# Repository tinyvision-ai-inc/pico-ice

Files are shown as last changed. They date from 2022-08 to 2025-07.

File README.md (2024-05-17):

# pico-ice

[Doc](http://pico-ice.tinyvision.ai/)
| [Hardware](https://github.com/tinyvision-ai-inc/pico-ice)
| [SDK](https://github.com/tinyvision-ai-inc/pico-ice-sdk)
| [Schematic](https://raw.githubusercontent.com/tinyvision-ai-inc/pico-ice/main/Board/Rev3/pico-ice.pdf)
| [Assembly](https://htmlpreview.github.io/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)
| [Discord](https://discord.gg/t2CzbAYeD2)

Elecrow (https://www.elecrow.com/pico-ice-rp2040-plus-lattice-ice40up5k-fpga.html)



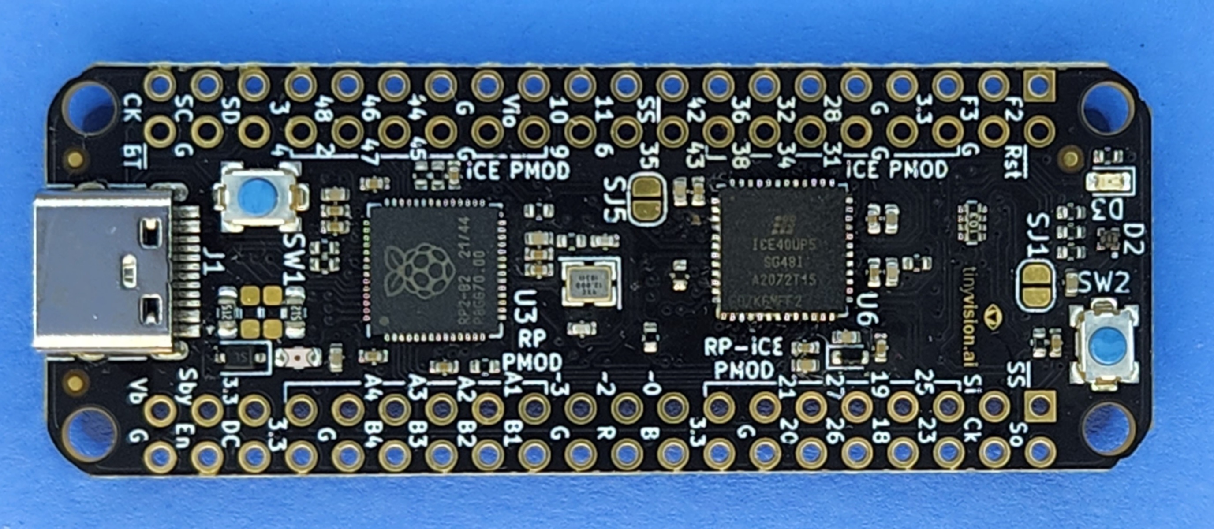
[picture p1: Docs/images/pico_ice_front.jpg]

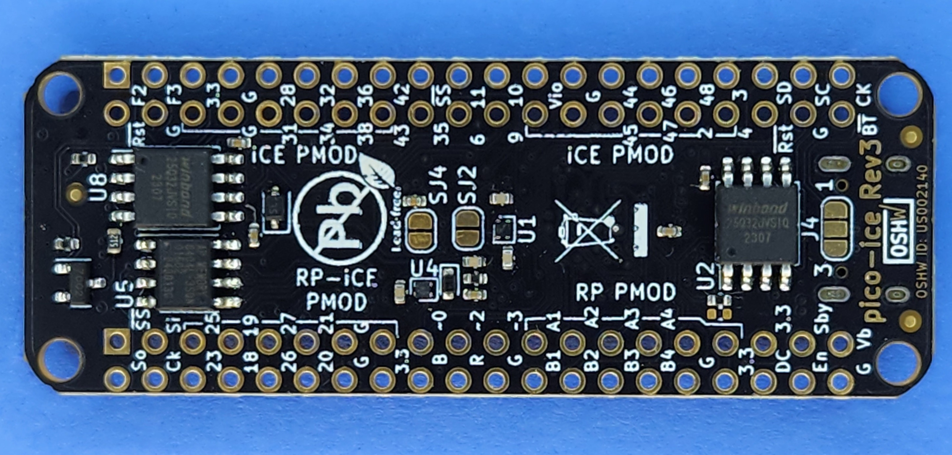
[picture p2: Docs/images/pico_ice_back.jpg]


## PCB Design Files, Designs, Documentation

The pico-ice is a small, low cost board with the Raspberry Pi Pico processor (RP2040) and a Lattice Semiconductor iCE40UP5K FPGA. The board features independent flash for the FPGA and RP2040, low power SSRAM, a couple of pushbuttons and a 3 color LED with _all_ FPGA and RP2040 pins brought out to easy to use 0.1" header pins (arranged as PMOD's) for fast prototyping.

The tinyVision.ai pico-ice Board Features:

* RaspberryPi RP2040 processor
* Lattice UltraPlus ICE40UP5K FPGA with 5.3K LUTs, 1Mb SPRAM, 120Kb DPRAM, 8 Multipliers
* _ALL_ RP2040 and 32 FPGA GPIO on 0.1” headers
* 4MB SPI Flash
* 8MB low power qSPI SRAM
* RGB LED, shared between the RP2040 and FPGA
* 2 pushbuttons, 1 dedicated and 1 primarily for processor reset during development but can be repurposed for user applications when not used for reset
* On board 3.3V and 1.2V Regulators, can supply 3.3V to your project
* Open source schematic and layout using KiCAD design tools
* 4 layer board with a solid ground plane for good signal integrity
* FPGA clock supplied by the RP2040, easy to program FPGA clock under SW control
* Examples for communicating to the FPGA over SPI
* Support for ultra low power sleeep mode: can shut down the RP2040 and FPGA while keeping the SRAM powered

Firmware features:
* pico-ice library to support drag-drop programming of the FPGA bitfile: no need of any dedicated programmer
* Alternate programming of the FPGA flash using DFU mode
* FPGA clock under RP2040 control
* Passthrough UART code enables transparent access to the FPGA's UART for debug/logging/control

[OSHW US002140](https://certification.oshwa.org/us002140.html) | Certified open source hardware | oshwa.org/cert

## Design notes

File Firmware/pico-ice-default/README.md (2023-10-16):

# Default Firmware

Downloads: [releases](https://github.com/tinyvision-ai-inc/pico-ice/releases/)

- A first USB-UART (#0) is used for the and a REPL command line interface
  for now only showing help message and version information.

- A second USB-UART (#1) is used for mirroring everything between
  this USB interface UART TX on RP0 with ICE27, UART RX on RP1 with ICE25.

- A third USB-UART (#2) is exchanging data with the main SPI bus onboard
  ([doc](https://pico-ice.tinyvision.ai/ice_usb.html#usb-spi-fpgasramflash-forwarding)).

- A 12 MHz clock is exported from the RP2040 pin 24 toward the iCE40 pin 35.

- An USB DFU interface allows programming through [dfu-utils](https://dfu-util.sourceforge.net/)
  as shipped with [oss-cad-suite](https://github.com/YosysHQ/oss-cad-suite-build).

- An USB MSC interface allows programming the board by copying a file to an USB device
  ([doc](https://pico-ice.tinyvision.ai/programming_the_fpga.html#using-a-drag-drop-or-file-copy-scheme)).

See the [documentation](https://pico-ice.tinyvision.ai/) for how to use them.

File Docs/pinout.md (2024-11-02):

# Pinout Diagram

This diagram shows the ICE40 and RP2040 names for the through holes on the pico-ice board. 

pinout diagram

[SVG](pinout/pinout.svg)
| [PNG](pinout/pinout.png)
| [RP2040](https://www.raspberrypi.com/documentation/pico-sdk/hardware.html#autotoc_md0)
| [ICE40](https://www.latticesemi.com/view_document?document_id=51971)

## With RTL on the iCE40

To program the FPGA, one needs to tell the synthesis tools which pins to connect to the signals in your RTL.  There are two different ways to name the pins.   The wafer names are words like `IOB_6a` and `IOT_8b`, and the pin numbers have names like `ICE_2`, `ICE_3`, and `ICE_4`.
Both sets of names can be found in this [PCF file](https://github.com/tinyvision-ai-inc/pico-ice-sdk/blob/main/rtl/pico_ice.pcf).

For Amaranth, until this gets upstreamed, the various board resources including its pins are defined on
[`pico_ice.py`](https://github.com/tinyvision-ai-inc/pico-ice-sdk/blob/main/amaranth/pico_ice.py).

## With code on the RP2040

The FPGA pins and other signals are defined in [`pico_ice.h`](https://github.com/tinyvision-ai-inc/pico-ice-sdk/blob/main/include/boards/pico_ice.h).

The PMOD pins can also be accessed from
[`pmod.h`](https://github.com/tinyvision-ai-inc/pico-ice-sdk/blob/main/include/pmod.h) and
[`ice_pmod.h`](https://github.com/tinyvision-ai-inc/pico-ice-sdk/blob/main/include/ice_pmod.h).

## SPI Pinouts 

For debugging the FPGA <-> SPI <-> Flash/RAM interface it is very helpful to use the 4 through holes on the upper right of the FPGA, and to connect a logic analyzer to the upper right PMOD.  These two diagrams may help.  Remember that the default boot process leaves the Flash switched ``off``.  With the Yosys icepack command, the ``-s`` option boots the Flash in the ``on`` state. 

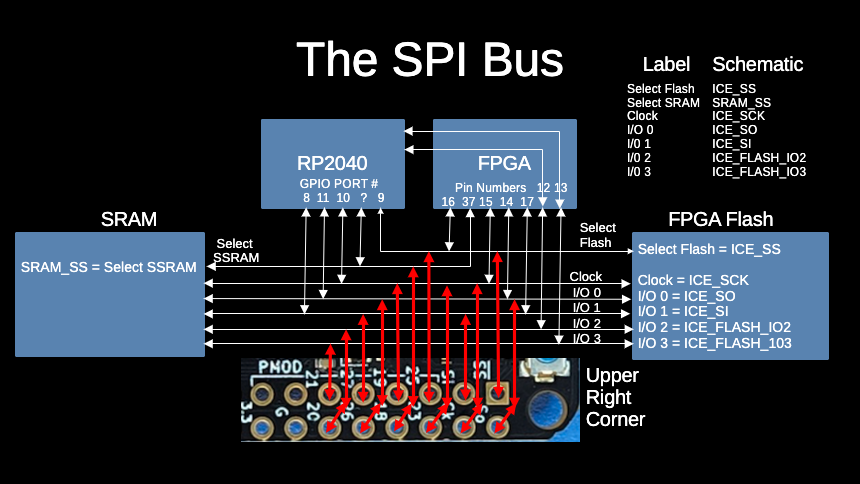
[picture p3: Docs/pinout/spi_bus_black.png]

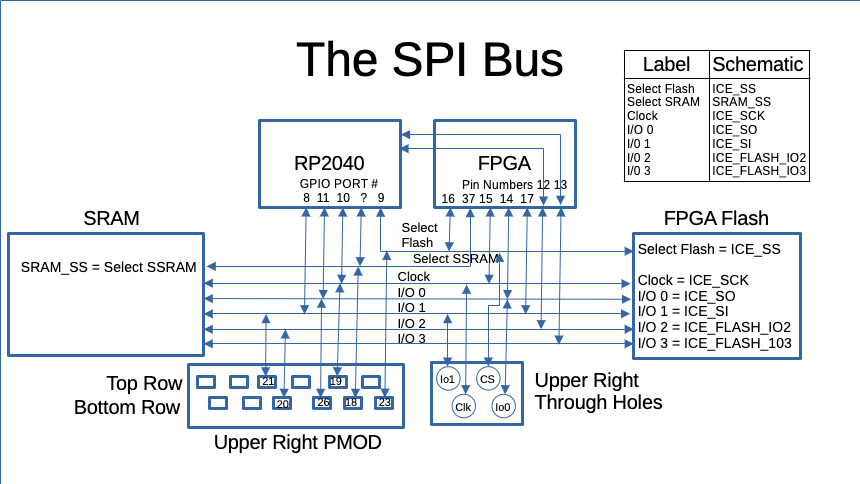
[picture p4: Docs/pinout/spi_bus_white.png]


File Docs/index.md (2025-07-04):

[Doc](http://pico-ice.tinyvision.ai/)
| [Hardware](https://github.com/tinyvision-ai-inc/pico-ice)
| [SDK](https://github.com/tinyvision-ai-inc/pico-ice-sdk)
| [Schematic](https://raw.githubusercontent.com/tinyvision-ai-inc/pico-ice/main/Board/Rev3/pico-ice.pdf)
| [Assembly](https://htmlpreview.github.io/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)
| [Discord](https://discord.gg/t2CzbAYeD2)

Elecrow (https://www.elecrow.com/pico-ice-rp2040-plus-lattice-ice40up5k-fpga.html)



The pico-ice is a small, low cost board with the Raspberry Pi Pico processor ([RP2040](https://www.raspberrypi.com/documentation/microcontrollers/rp2040.html)) and a Lattice Semiconductor [iCE40UP5K](https://www.latticesemi.com/en/Products/FPGAandCPLD/iCE40UltraPlus) FPGA. The board features independent flash for the FPGA and RP2040, low power SSRAM, a couple of pushbuttons and a 3 color LED with _all_ FPGA and RP2040 pins brought out to easy to use 0.1" header pins (arranged as Pmod's) for fast prototyping.




Board Hardware Features:

* Raspberry Pi RP2040 processor
* Lattice UltraPlus ICE40UP5K FPGA with 5.3k LUTs, 1Mb SPRAM, 120Kb DPRAM, 8 Multipliers
* _ALL_ RP2040 and 32 FPGA GPIO on 0.1” headers
* 4MB SPI Flash
* 8MB low power qSPI SRAM
* RGB LED, shared between the RP2040 and FPGA
* 2 pushbuttons, 1 dedicated and 1 primarily for processor reset during development but can be repurposed for user applications when not used for reset
* On board 3.3V and 1.2V Regulators, can supply 3.3V to your project
* Open source schematic and layout using KiCAD design tools
* 4 layer board with a solid ground plane for good signal integrity

Board Firmware features:

* FPGA clock supplied by the RP2040, easy to program FPGA clock under SW control
* RP2040 can program the FPGA in various ways
* Examples for communicating to the FPGA from USB to UART or SPI
* Support for ultra low power sleeep mode: can shut down the RP2040 and FPGA while keeping the SRAM powered

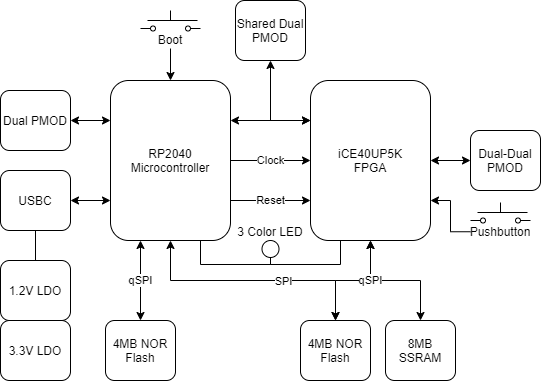
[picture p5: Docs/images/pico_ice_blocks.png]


[OSHW US002140](https://certification.oshwa.org/us002140.html) | Certified open source hardware | oshwa.org/cert

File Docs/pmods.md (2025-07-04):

# Using Pmods

The Pmod Connection system is using a grid of 2 rows and 6 columns of pins.

It was designed by Digilent to offer something compatible with both classical jumper wires used on breadboards,
and a standardised pinout that supports multiple protocols on the same connector.

This is popular on FPGA boards as it permits them to support any protocol over
the same connector with the right pinout, rarely possible on MCUs.

This standard is documented [here](https://reference.digilentinc.com/_media/reference/pmod/pmodoledrgb/pmodoledrgb_sch.pdf).

## Pmod in the pico-ice

Here is an [example of how to solder](md_getting__started.html#autotoc_md2) the Pmod connectors.

There are 4 Pmod connectors in the pico-ice, numbered clockwise from 1 to 4 starting from the USB connector.

- 2 connected to the iCE40
- 1 connected to both the RP2040 and iCE40
- 1 connected to the RP2040

The pinout of the RP2040 is made to be compatible with SPI0,
with the other protocols that may be bit-banged or implemented with PIO to be pin-compatible.

For the iCE40, the pin numbers are available from
[pico_ice.pcf](https://github.com/tinyvision-ai-inc/pico-ice-sdk/blob/main/rtl/pico_ice.pcf).

For the RP2040, the pin numbers are available from
[ice_pmod.h](https://github.com/tinyvision-ai-inc/pico-ice-sdk/blob/main/include/ice_pmod.h).

You can then use any of the pinout declaration described
[here](https://github.com/tinyvision-ai-inc/pico-ice-sdk/blob/main/include/pmod.h).

    // Use the pins from their GPIO names
    gpio_init(ice_pmod_3.gpio.io1);
    gpio_init(ice_pmod_3.gpio.io2);
    gpio_init(ice_pmod_3.gpio.io3);
    gpio_init(ice_pmod_3.gpio.io4);
    gpio_init(ice_pmod_3.gpio.io7);
    gpio_init(ice_pmod_3.gpio.io8);
    gpio_init(ice_pmod_3.gpio.io9);
    gpio_init(ice_pmod_3.gpio.io10);

    // Use the pins from their I²C names
    gpio_init(ice_pmod_3.i2c.sda);
    gpio_init(ice_pmod_3.i2c.scl);

    // Use the pins from their UART names
    gpio_init(ice_pmod_3.i2c.tx);
    gpio_init(ice_pmod_3.i2c.rx);

    // Use the pins from their SPI names
    gpio_set_function(ice_pmod_3.spi.copi, FUNC_SPI);
    gpio_set_function(ice_pmod_3.spi.cipo, FUNC_SPI);
    gpio_set_function(ice_pmod_3.spi.clk, FUNC_SPI);

    // Access the top or bottom row individually
    gpio_set_function(ice_pmod_3.row.top.spi.copi, FUNC_SPI);
    gpio_set_function(ice_pmod_3.row.bottom.spi.copi, FUNC_SPI);

    [...]

## Pmod Modules

There are many Pmod vendors, and this page attempts to enumerate as many as possible.

If you have made a Pmod module, let us know and we would add it to this list!

- <https://www.infineon.com/cms/en/search.html#!term=pmod&view=products>
- <https://digilent.com/shop/boards-and-components/system-board-expansion-modules/pmods/>
- <https://www.renesas.com/us/en/software-tool/quick-connect-iot-platform>
- <https://www.tindie.com/stores/johnnywu/>
- <https://1bitsquared.com/collections/fpga>
- <https://www.tindie.com/search/?q=pmod>
- <https://lectronz.com/products/search?q=pmod>
- <https://www.aries-embedded.com/evaluation-kit/tools/pmod-extension-module>
- <https://github.com/wuxx/icesugar/tree/master/schematic>
- <https://machdyne.com/?s=pmod&post_type=product>
- <https://aliexpress.com/store/912189181/search?SearchText=pmod>
- <https://github.com/swetland/ethernet-pmod>
- <https://fpga.fm4dd.com/>
- <https://github.com/icebreaker-fpga/icebreaker-pmod>
- <https://blackmesalabs.wordpress.com/>
- <https://www.solder.party/docs/keyboard-pmod/pmod-to-qwiic-adapter/>
- <https://github.com/marcinwachowiak/pmod-pdm-microphone-array/>
- <https://github.com/apfelaudio/eurorack-pmod>

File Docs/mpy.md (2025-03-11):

# Micropython

Pico-ice and pico2-ice support micropython.

## To install
- Acquire the latest release for the device you have from: https://github.com/tinyvision-ai-inc/pico-ice-micropython/releases
- Flash the device as normal (uf2 pasted in the RP2 disk)

## To use
The API to use the FPGA is as follow:
- `ice` is the microypthon module: `import ice`
- `fpga` is the class provided by the module to manage the ICE40 FPGA `ice.fpga(...)`
- `fpga` provides the methods `stop()`, `start()`, and `cram(file)`

## How to program a bitstream to the FPGA RAM

- The Pin class is imported from the machine module to provide interfacing with the hardware.
- The module is imported
- The fpga type is configured with the approriate pins for the device, as well as the frequency (in MHz) that the FPGA will run at.
- The bitstream file is opened, in byte (as opposed to text) mode (`b`), to read (`r`).
- The fpga is brought out of reset with `fpga.start()`
- The bitstream is loaded into the FPGA using `fpga.cram(file)` with the previously opened file as argument.

### On pico-ice:

```python
from machine import Pin
import ice
fpga = ice.fpga(cdone=Pin(26), clock=Pin(24), creset=Pin(27), cram_cs=Pin(9), cram_mosi=Pin(8), cram_sck=Pin(10), frequency=48)
file = open("bitstream.bin", "br")
fpga.start()
fpga.cram(file)
```

### On pico2-ice:

```python
from machine import Pin
import ice
fpga = ice.fpga(cdone=Pin(40), clock=Pin(21), creset=Pin(31), cram_cs=Pin(5), cram_mosi=Pin(4), cram_sck=Pin(6), frequency=48)
file = open("bitstream.bin", "br")
fpga.start()
fpga.cram(file)
```

## How to program a bistream to the FPGA Flash (persistent bitstream)

### On pico-ice:

```python
from machine import Pin
import ice
file = open("bitstream.bin", "br")
flash = ice.flash(miso=Pin(8), mosi=Pin(11), sck=Pin(10), cs=Pin(9))
flash.erase(4096) # Optional
flash.write(file)
# Optional
fpga = ice.fpga(cdone=Pin(26), clock=Pin(24), creset=Pin(27), cram_cs=Pin(9), cram_mosi=Pin(8), cram_sck=Pin(10), frequency=48)
fpga.start()
```

### On pico2-ice:

```python
from machine import Pin
import ice
file = open("bitstream.bin", "br")
flash = ice.flash(miso=Pin(4), mosi=Pin(7), sck=Pin(6), cs=Pin(5))
flash.erase(4096) # Optional
flash.write(file)
# Optional
fpga = ice.fpga(cdone=Pin(40), clock=Pin(21), creset=Pin(31), cram_cs=Pin(5), cram_mosi=Pin(4), cram_sck=Pin(6), frequency=48)
fpga.start()
```

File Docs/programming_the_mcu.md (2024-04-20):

# Programming the RP2040

To upload a new firmware image on the PR2040 (the "pico" part of "pico-ice"), you need to switch to that RP2040 UF2 bootloader mode instead of the FPGA UF2 mode.

You can do that by connecting a jumper between the `BT` pin a `Gnd` pin, then press the `RESET` button:

1. Connect the `USB_BOOT` pin to ground. For instance with a pair of tweezers, a jumper, or an uncoated paper clip.

2. Press and release the "RESET" button. The RP2040 now bypasses its firmware, and runs the RP2040 factory bootloader (from internal ROM) instead.

3. Disconnect the `USB_BOOT` pin from ground.

4. Look for an USB drive named `RPI-RP2` and mount it, open it, and check that there are only 2 files in it: `INFO.HTML` and `INFO_UF2.TXT`.
   If you also have an `CURRENT.UF2`, this means you found the FPGA flashing interface, and need to retry steps 1 and 2.

5. Copy the `.uf2` firmware file onto the USB drive.

6. Eject the USB drive.
   At this step, the firmware should be uploaded and running.

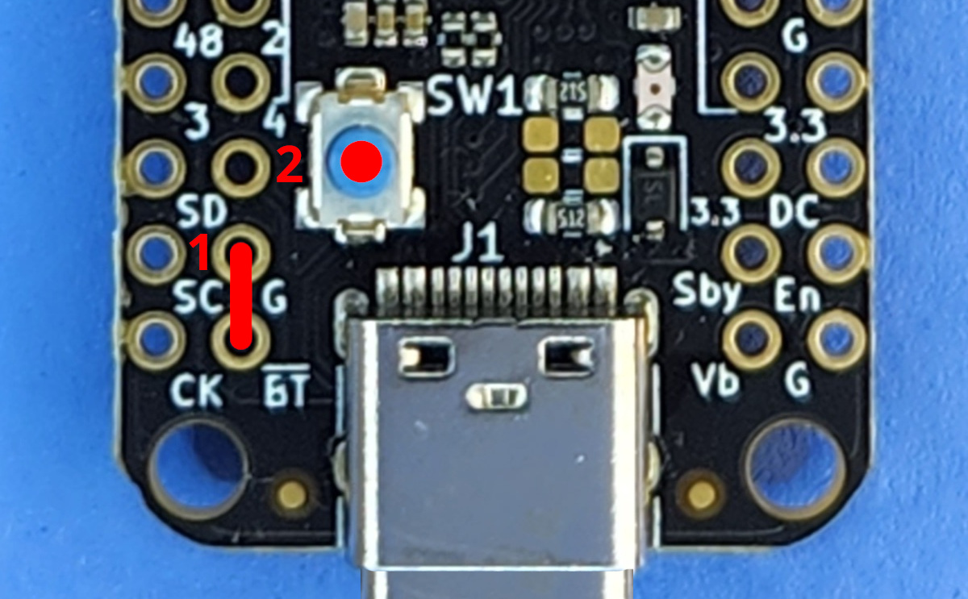
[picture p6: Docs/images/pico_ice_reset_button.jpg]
photo of which pins to short


Since version [`v1.6.1`](https://github.com/tinyvision-ai-inc/pico-ice/releases),
it is possible to reboot the pico-ice into bootloader "BOOTSEL" mode without jumpers:

    picocom --baud 1200 /dev/ttyACM0

This uses the [convention established by Arduino boards](https://arduino.github.io/arduino-cli/dev/platform-specification/#1200-bps-bootloader-reset)
which reset into bootloader mode when connecting with baud 1200.

After this, it becomes possible to use the [picotool](https://github.com/raspberrypi/picotool) to control the firmware (upload, check version, reboot):

    $ sudo picotool info
    Program Information
     name:      pico_ice_default
     features:  USB stdin / stdout

## Troubleshooting

### RPI-RP2 is still visible after step 6

This means the device remained in "bootloader" mode.
One thing to check is that the `USB_BOOT` pin (marked `BT` on the board) is not connected to anything anymore,
then try to reset the board.

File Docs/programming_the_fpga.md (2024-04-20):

# Programming the iCE40

The FPGA normally boots from a dedicated serial NOR flash.
This flash can be programmed by the Pico processor which exposes the flash to the host OS as either a removable drive or a DFU endpoint.

On Windows, while the RaspberryPi guide mentions using Visual Studio Code with a plugin a an IDE, better results were obtained by using the [WSL2 environment](https://learn.microsoft.com/en-us/windows/wsl/install).

## Using a drag and drop file copy

You would need a compiler toolchain installed for building the [UF2 Utils](https://github.com/tinyvision-ai-inc/uf2-utils) on your system.
On Windows, you can use <https://github.com/microsoft/uf2> instead,
which contains [uf2conv.py](https://github.com/microsoft/uf2/blob/master/utils/uf2conv.md).

Out of the box, the [default firmware](https://github.com/tinyvision-ai-inc/pico-ice/releases/) should already be present on your board.
You can skip step 1 if this is the case.

1.  If you changed the default firwmare, [program](md_programming__the__mcu.html) it again onto the RP2040.
    You can also integrate the FPGA programming code in your own firmware with [ice_usb](group__ice__usb.html).

2.  Install or build the [UF2 Utils](https://github.com/tinyvision-ai-inc/uf2-utils),
    and a [blinky example](https://github.com/tinyvision-ai-inc/UPduino-v3.0/blob/master/RTL/blink_led/rgb_blink.bin) for any iCE40 board.

3.  Convert the binary bitstream `rgb_blink.bin` into an UF2 `rgb_blink.uf2` with the UF2 Utils:

        $ bin2uf2 -o rgb_blink.uf2 rgb_blink.bin

4.  Connect the pico-ice via USB and lookup the USB drive named `pico-ice`. Open it.

5.  You can copy the `rgb_blink.uf2` file to that drive you just attached.
    As soon as you copy the file over,t he pico-ice will reboot and allow the FPGA to come up depending on the code running in the Pico processor.

## Using the DFU mode

1.  If you changed the default firwmare, [program](md_programming__the__mcu.html) it again onto the RP2040.
    You can also integrate the FPGA programming code in your own firmware with [ice_usb](group__ice__usb.html).

2.  Install the DFU utilities.

    a.  For Windows, [yosys-hq tabby-cad](https://www.yosyshq.com/tabby-cad-datasheet):
        double-clicking on `start.bat` on the OSS CAD Suite installation opens a prompt with the dfu-util command available.

    b.  For other systems you can install the [dfu-util](https://repology.org/project/dfu-util/versions) package.

3.  Check whether the Pico is recognized as a DFU device: `dfu-util -l`.
    This should list the pico-ice as a DFU device:

        Found DFU: [1209:b1c0] ver=0100, devnum=105, cfg=1, intf=0, path="1-4.4", alt=0, name="iCE40 DFU (flash)", serial="DE62A435436F5939"
        Found DFU: [1209:b1c0] ver=0100, devnum=105, cfg=1, intf=0, path="1-4.4", alt=1, name="iCE40 DFU (CRAM)", serial="DE62A435436F5939"

4.  Download the FPGA bin file to the pico-ice.
    The Pico can be rebooted as soon as the download succeeds with the `-R` flag.

        $ dfu-util --alt 0 --download rgb_blink.bin --reset  # to flash
        $ dfu-util --alt 1 --download rgb_blink.bin          # to volatile memory

## Using APIO

The [APIO](https://github.com/FPGAwars/apio) project is a command line tool to fetch and use
the [oss-cad-suite](https://github.com/YosysHQ/oss-cad-suite-build) FPGA toolchain based
on [Yosys](https://github.com/YosysHQ/).

It will bring an up-to-date build environment running quickly.

On Windows, you will first need to setup the `libusbK` driver for `pico-ice DFU (CRAM)`
[with Zadig](https://zadig.akeo.ie/) or [with UsbDriverTool](https://visualgdb.com/UsbDriverTool/)
([doc](https://github.com/FPGAwars/apio/wiki/Quick-start)).

    # Download the latest APIO dev version (with pico-ice support):
    pip3 install git+https://github.com/FPGAwars/apio

    # Download and install oss-cad-suite
    apio install -a
    
    # Build a new directory with a "blinky" example project inside
    mkdir pico-ice-blinky; cd pico-ice-blinky
    apio examples -f iCE40-UP5K/blink

    # Set the board to "pico-ice"
    apio init --sayyes --board pico-ice

    # Build the project using yosys/nextpnr
    apio build

    # Plug your pico-ice board and upload the blinky project to it
    apio upload

If `apio upload` fails, it is also possible to convert the `.bin` file to `.uf2`
with [uf2-utils](https://github.com/tinyvision-ai-inc/uf2-utils/)
or [uf2conv.py](https://github.com/microsoft/uf2/blob/master/utils/uf2conv.md):
[doc](md_programming__the__fpga.html#autotoc_md28).

## Using OSS CAD Suite

The [OSS CAD Suite](https://github.com/YosysHQ/oss-cad-suite-build) project is a pre-compiled package of several tools.
It provides a complete solution for building, debugging, simulating, uploading Hardware Description Language (HDL).
It is based on [Yosys](https://github.com/YosysHQ/).

As explained on the [installation](https://github.com/YosysHQ/oss-cad-suite-build#installation) instructions,
you can download it and extract it to a directory of your choice.

Several pico-ice-sdk [examples](https://github.com/tinyvision-ai-inc/pico-ice-sdk/tree/main/examples) rely on a
`$OSS_CAD_SUITE` variable set to the full path where you extracted these files.

On Windows, you can run these examples from the cygwin environment,
under which you can navigate to the example repositories and try them.

You can access the utilities directly from a shell environment after adding the
`$OSS_CAD_SUITE` to the `$PATH`.

If you used `apio` to install OSS CAD Suite:

    export OSS_CAD_SUITE="$HOME/.apio/packages/tools-oss-cad-suite"
    export PATH="$PATH:$OSS_CAD_SUITE/bin"

## Troubleshooting

### Checking the CDONE pin

Once the FPGA bitfile transfers over using the DFU protocol,
the Pico will check for whether the DONE pin goes high indicating a successful boot.
This would make the CDONE green LED bright.
If this doesnt happen for whatever reason,
the DFU utility will throw an error indicating that this did not succeed.

### Booting the FPGA with custom firmware

The user writing a custom firmware with the pico-ice-sdk should take care of starting the FPGA from the MCU.
Review the [pico_fpga](https://github.com/tinyvision-ai-inc/pico-ice-sdk/tree/main/examples/pico_fpga) example
for how this can be done, as well as the [ice_fpga](group__ice__fpga.html) library documentation.
The USB DFU provided as part of the pico-ice-sdk must also be enabled for the DFU interface to show-up.
The [pico_usb_uart example](https://github.com/tinyvision-ai-inc/pico-ice-sdk/tree/main/examples/pico_usb_uart) project have it enabled by default.

### Cannot open DFU device 1209:b1c0 found on devnum 61 (LIBUSB_ERROR_NOT_FOUND)

This error might occur when a communication error occurs.

- On Windows operating system, the device needs to be declared with [Zadig](https://zadig.akeo.ie/) as described [here](https://github.com/pbatard/libwdi/wiki/Zadig#basic-usage).
  Make sure to select the pico-ice device on the list rather than any other to avoid erasing your system's USB drivers.

- On Linux operating system, it might need to be allowed with an udev rule,
  or `dfu-util` might need to be run as super user.

To create an udev rule, add a file named `/etc/udev/rules.d/99-pico-ice.rules` with this content:

    SUBSYSTEM=="usb", ATTRS{idVendor}=="1209", ATTRS{idProduct}=="b1c0", MODE="0666"

Then reboot or run the following commands:

    sudo udevadm control --reload-rules
    sudo udevadm trigger

### dfu-util has multiple devices

For devices with multiple DFU devices connected, the `--device 1209:b1c0` flag is needed:

    dfu-util --alt 0 --download rgb_blink.bin --reset --device 1209:b1c0

Alternatively, the `dfu-util --list` result will allow selecting a device per number:

    dfu-util --alt 0 --download rgb_blink.bin --reset --devnum 0

### dfu-util is stuck while uploading before anything could be sent

This could be due that there was no response from the flash chip, and the RP2040 is endlessy waiting the write confirmation.
If you had an earlier board, it could be due to the fact the TX and RX pins were swapped, and do not work for the old board anymore.

### Flashing an UF2 file does not change the memory neither restart the board

The UF2 file format contains the destination addresses of each block.
In case you used other tools than those provided,
it is possible that that the addresses were outside the valid range of the flash chip.
Try to copy the CURRENT.UF2 to NEW.UF2 upon that same directory, and unmount the device.
This should trigger a restart of the device.
This restart device should appear from the debug UART: `board_dfu_complete: rebooting`.

### Device's firmware is corrupt. It cannot return to run-time (non-DFU) operations.

This message sometimes comes from `dfu-util` when the `-R` flag is not used.
With the `-R` flag, the pico-ice will reboot at the end of the transfer,
and DFU-util should not complain anymore.

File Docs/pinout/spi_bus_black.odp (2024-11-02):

## The SPI Bus

Label | Schematic
Select Flash Select SRAM Clock I/O 0 I/0 1 I/0 2 I/0 3 | ICE_SS SRAM_SS ICE_SCK ICE_SO ICE_SI ICE_FLASH_IO2 ICE_FLASH_IO3

FPGA Flash

Select Flash = ICE_SS

Clock = ICE_SCK

I/O 0 = ICE_SO

I/O 1 = ICE_SI

I/O 2 = ICE_FLASH_IO2

I/O 3 = ICE_FLASH_103

Upper

Right

Corner

RP2040

GPIO PORT #

8 11 10 ? 9

FPGA

Pin Numbers 12 13

16 37 15 14 17

SRAM

Select

Flash

Clock

SRAM_SS = Select SSRAM

Select

SSRAM

I/O 1

I/O 0

I/O 2

I/O 3

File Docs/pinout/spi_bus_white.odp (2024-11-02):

## The SPI Bus

Label | Schematic
Select Flash Select SRAM Clock I/O 0 I/0 1 I/0 2 I/0 3 | ICE_SS SRAM_SS ICE_SCK ICE_SO ICE_SI ICE_FLASH_IO2 ICE_FLASH_IO3

FPGA Flash

Select Flash = ICE_SS

Clock = ICE_SCK

I/O 0 = ICE_SO

I/O 1 = ICE_SI

I/O 2 = ICE_FLASH_IO2

I/O 3 = ICE_FLASH_103

RP2040

GPIO PORT #

8 11 10 ? 9

FPGA

Pin Numbers 12 13

16 37 15 14 17

Select SSRAM

SRAM

Select

Flash

Clock

SRAM_SS = Select SSRAM

I/O 1

I/O 0

I/O 2

I/O 3

Top Row

Upper Right PMOD

21

19

Io1

CS

Upper Right

Through Holes

Bottom Row

20

26

18

23

Clk

Io0

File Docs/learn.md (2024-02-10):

# Learning FPGA Design

A large number of resources exists for learning FPGA design.

Some of them have been collected and aggregated on this page.

An online class was held by tinyVision.ai, and is available freely:

- [Hands-on-FPGA-class](https://github.com/tinyvision-ai-inc/Hands-on-FPGA-class/)

## Video format

- [Digi-Key Intro to FPGA](https://www.youtube.com/watch?v=lLg1AgA2Xoo)
  Starts with defining FPGA and covers HDLs, programming flow etc.
  New to FPGAs? Start here!

- [SystemVerilog in 5 minutes](https://www.bilibili.com/video/BV1Rr4y1z7Dv?p=1)
  Serie of concise and focused descriptions of the SystemVerilog language.

- [VLSI Chaps](https://youtube.com/channel/UCzvXC7WbnaWs5FZ5djO8cag)
  Discussion and explanation of ASICs, VLISI, but also SystemVerilog.

- [Digital to FPGA 101](https://youtu.be/FcFbFTbngrw)
  design a circuit in digital convert into verilog and run it on an ice40 FPGA (like Upduino_v3.1).

## Examples

- [icebreaker-verilog-examples](https://github.com/icebreaker-fpga/icebreaker-verilog-examples)
  A collection of examples using Makefiles for iCE40 boards.
  Can be used for the `pico-ice` with minor adaptations.

- [Xark's upduino-example](https://github.com/XarkLabs/upduino-example/tree/master)
  An example for how to use a Makefile for building a Verilog.
  Can be used for the `pico-ice` with minor adaptations.

- [tnt's ice40-playground](https://github.com/smunaut/ice40-playground/)
  S. Munaut's examples for the iCE40.

- [Librecores](https://www.librecores.org/)
  Index of open source cores (Verilog, VHDL...) projects. Good Verilog examples.

- [Upduino v2 icestorm examples](https://github.com/osresearch/up5k)
  large collection of very useful code, and a good overview. Upduino v2 only.

## General tutorials

- [Hobbyist's guide to FPGAs](https://hackaday.io/project/27550-the-hobbyists-guide-to-fpgas)
  FPGA tutorials, theory of design articles, hands-on labs targeted towards hobbyists.

- [VHDL Wiz](https://vhdlwhiz.com/)
  Community offering tutoring focused on VHDL.

- [Hardware as Code](https://www.hackster.io/sthibault/hardware-as-code-part-i-an-introduction-48bacb)
  A 5-part tutorial series using the UPduino as an example.

- [fpga 101 fpgas for beginners](https://www.nandland.com/articles/fpga-101-fpgas-for-beginners.html)
  Tutorial explaining concepts and practice with videos and articles.

- [Alchitry](https://alchitry.com/)
  Tutorial focused on the Artix 7 Alchitry boards.

- [Fomu Workshop](https://workshop.fomu.im/en/latest/)
  Workshop by FOMU the ICE40 FPGA that fits on an USB port.

- [Open FPGA Verilog Tutorial](https://github.com/Obijuan/open-fpga-verilog-tutorial/wiki)
  Excellent tutorial series for beginners and the more experienced.

- [Atadiat](https://atadiat.com/en/)
  Introduction about FPGA in both English and Arabic languages.

- [Verilog Tutorial for beginners](http://www.referencedesigner.com/tutorials/verilog/verilog_01.php)
  Verilog Tutorial Series.

- [CircuitVerse](https://learn.circuitverse.org/)
  Teaching verilog through an interactive book with challenges along the way.

- [ASIC-World Tutorial on Verilog](https://www.asic-world.com/verilog/veritut.html)
  Introduction to Verilog oriented toward ASICs and chip design.

- [FPGA-4-fun](https://www.fpga4fun.com/)
  Tutorials covering many practical problems with FPGAs.
  Lots of info and very well put together

- [Lattice IceCube2 Tutorial](https://hsel.co.uk/2018/05/21/lattice-ice40-ultra-plus-fpga-gnarly-grey-upduino-tutorial-1-the-basics/)
  A tutorial on Lattice's IceCube2 software/ide.
  IceCube2 is no longer recommended, replaced by Radiant

- [VLSI Chaps](https://youtube.com/channel/UCzvXC7WbnaWs5FZ5djO8cag)
  Discussion and explanation of ASICs, VLISI, but also SystemVerilog.

- [Digital to FPGA 101](https://youtu.be/FcFbFTbngrw)
  design a circuit in digital convert into verilog and run it on an ice40 FPGA (like Upduino_v3.1).

- [Verilog Tutorial](http://www.asic-world.com/verilog/veritut.html)
  Tutorial series on verilog with example code.
  all examples are synthesizable in icarus verilog simulator

- [CFU Playground](https://cfu-playground.readthedocs.io/en/latest/)
  The "Crash Course on Everything" is a good introduction

- [VHDL in an hour](https://www.jopdesign.com/teaching/VHDL.pdf)
  Fast paced but practical guide to VHDL.
  longest hour ever

- [First look at Prog. Logic](https://www.allaboutcircuits.com/technical-articles/a-microcontroller-enthusiast-first-look-at-programmable-logic/)
  Getting started w/FPGAs article series 1.

- [Sparkfun So you want to learn FPGAs](https://www.sparkfun.com/news/1203)
  Sparkfun article introducing to FPGAs.

- [ZIPCPU](http://zipcpu.com/)
  Articles by Gisselquist explaining design,verification, and more.

- [FPGA Workshop](https://github.com/ranzbak/fpga-workshop)
  Basic FPGA development for absolute beginners featuring the Upduino V2.

- [Upduino FPGA Tutorial](https://blog.idorobots.org/entries/upduino-fpga-tutorial.html)
  UPduino FPGA tutorial using APIO.

- [Installing the Icestorm Toolchain](https://www.youtube.com/watch?v=Bfhnu9XUzLs)
  Guide on getting comfortable with a Makefile-based development process for Icestorm/Yosys and Verilog.

- [Explanation of essential Verilog concepts](https://vanhunteradams.com/DE1/Lorenz/Verilog.html)
  Several pitfalls and myths debunked about the Verilog language, as part of an introduction.

## Specific topic

- [clock domain crossing](http://fpgacpu.ca/fpga/handshake.html)
  Sending data across modules of two different clock domain: clock domain crossing.

- [lowRISC Verilog Coding Style](https://github.com/lowRISC/style-guides/blob/master/VerilogCodingStyle.md)
  Set of rules for formatting and organizing Verilog code.
  Not difficult per-se, but problem encountered after initial discovery of Verilog is over

- [Interfacing FPGAs to an ADC’s Digital Data Output](https://www.analog.com/en/technical-articles/interfacing-fpgas-to-an-adcs-digital-data-output.html)
  Article from Analog Design exploring the topic of ADC/DAC <-> FPGA interface.

- [RISC-V on an ICE40 FPGA](https://pingu98.wordpress.com/2019/04/08/)
  A very detailed blog on implementing a RISC-V in the FPGA.

- [RISC-V on an iCE40 FPGA](https://github.com/BrunoLevy/learn-fpga)
  by the author of the relatively high-performance yet tiny RISC-V core FemtoRV.

## Wiki

- [VHDL Wiz Terminology](https://vhdlwhiz.com/terminology/)
  Glossary of many concepts.

- [VHDL Wiz Terminology](https://vhdlwhiz.com/terminology/)
  Glossary of many concepts.

- [Hamsterworks wiki](https://web.archive.org/web/20190115080828/http://hamsterworks.co.nz/mediawiki/index.php/Main_Page)
  Introduction to FPGAs focused on VHDL.
  The site is offline, but an archive of the content is still available.

- [VerilogGuide](https://verilogguide.readthedocs.io/)
  Wiki/Book for learning Verilog from the ground up.
  Uses Quartus and ModelSim-Altera Starter instead of the open source toolchain

- [Chipress](https://chipress.online/)
  Collection of explanations targetted at aspiring ASICs engineers.
  Many of the topics are related

- [ChipVerify](https://www.chipverify.com/)
  Wiki covering much of Verilog and SystemVerilog syntax.

- [FPGA key](https://www.fpgakey.com/)
  Community focused on providing resources to learn FPGAs.

## Simulators

- [EDA playground](https://www.edaplayground.com/home)
  Online IDE and simulator, quickest way to get started without a dev board.

- [Verilator](https://www.veripool.org/verilator/)
  Simulator for Verilog code.
  Convert the simulation to a C++ code library that exposes signals as C variables.

- [Icarus Verilog](http://iverilog.icarus.com/)
  Simulator for Verilog code.

- [Digital](https://github.com/hneemann/Digital/releases)
  digital logic circuit simulator based on logisim.
  Alternative: https://github.com/logisim-evolution/logisim-evolution

- [HDL Bits](https://hdlbits.01xz.net/wiki/Main_Page)
  Interactive (in browser) verilog syntax lessons.
  initially assumes no prior knowledge of HDLs but quickly ramps up difficulty

## Toolchains

- [oss-tabby-cad](https://github.com/YosysHQ/oss-cad-suite-build)
  A complete toolchain based on top of Yosys.

- [Yosys](https://yosyshq.net/yosys/)
  The central tool connecting the languages front-end and back-ends.

- [GHDL](https://ghdl.github.io/ghdl/)
  Simulator for VHDL code.

- [MixedSim](https://www.isotel.eu/mixedsim/)
  Tool building on top of ngspice for simulating circuits.

- [verilog to routing](https://verilogtorouting.org/)
  Open-Source toolchain alternative to YoSys.

- [open FPGA](https://github.com/azonenberg/openfpga)
  Older toolchain for CPLD.

- [FASM](https://fasm.readthedocs.io/en/latest/)
  Low-level format aiming to be a de-facto industry standard for FPGA toolchains.

## Courses

- [Hands-on FPGA class](https://github.com/tinyvision-ai-inc/Hands-on-FPGA-class/)
  A 8-week class was given by tinyVision.ai for getting started with FPGAs.

- [Intel FPGA Academy](https://fpgacademy.org/courses.html)
  Digital logic/FPGA courses by Intel.
  requires .edu email (contact intel for access without .edu email but response may vary)

- [fpga4fun FPGAs 1 - What are they?](https://www.fpga4fun.com/FPGAinfo1.html)
  Intro to FPGA lesson 1.
  Link is forr lesson 1 of intro to FPGA but the entire site is dedicated to learning FPGAs

- [WTFpga Workshop](https://github.com/icebreaker-fpga/wtfpga)
  Guided discovery of FPGA through the IceBreaker board.

- [IceBreaker Workshop](https://github.com/icebreaker-fpga/icebreaker-workshop)
  Course focused on getting started through the IceBreaker board.

- [Intro to Digital Logic Circuits](http://www.ece.tufts.edu/es/4/)
  University course by Steven Bell that assumes little/no prior knowledge of FPGAs.
  Features the Upduino v3 and "Digital Design and Computer Architecture arm edition"

- [Digital System Design (DSD) Spring 2009](http://www.ee.ic.ac.uk/pcheung/teaching/ee3_DSD/)
  Course introducing FPGAs to students.

- [MIT 6.205 Course](https://fpga.mit.edu/6205/F22)
  Requires log-in to access the whole content, but good introductory text.

- [ECE 5760 Course](https://people.ece.cornell.edu/land/courses/ece5760/)
  A class that widely publishes their teaching material, allowing 3rd-party
  students to attempt it on their own.

## Other lists

- [F4PGA Link list](https://github.com/f4pga/ideas/issues/52)
  Another project aiming to collect links.

- [FPGA Design Elements](http://fpgacpu.ca/fpga/index.html)
  coding style and notes about various building blocks/design principles.
  Fantastic list of resources/code examples etc

- [HDL Simulators](https://en.wikipedia.org/wiki/List_of_HDL_simulators)
  Wikipedia list of simulators for HDLs.

- [sv-tests results](https://chipsalliance.github.io/sv-tests-results/)
  Table summarizing support for all SystemVerilog (and Verilog) features support in various tool..
  Useful to check compatibility of a toolchain

## Books

- [PLD World E-books](http://ebook.pldworld.com/_eBook/FPGA%EF%BC%8FHDL/-Eng-/)
  ebooks about all things HDL/FPGA/PLD etc.

- [Digital systems design using VHDL](https://www.pdfdrive.com/digital-systems-design-using-vhdl-d166870425.html)
  VHDL/digital design textbook by Charles H. Roth Jr & Lizy K. John.

- [FPGAs now what?](https://xess.com/static/media/appnotes/FpgasNowWhatBook.pdf)
  FPGA e-book that employs a hands on/learn by doing approach.

- [SystemVerilog RTL Modeling, Simulation, Verification](https://systemverilog.dev/)
  Online book on SystemVerilog using Cadence tools or EDA Playground.
  Work in progress

- [Digital Logic Pocket Data Book](https://www.ti.com/lit/ug/scyd013b/scyd013b.pdf)
  pinout/reference for TI Logic ICs (74xx series etc).
  Not exactly FPGA related, but useful for configuring the FPGA like common logic ICs

## Organizations

- [Build an FPGA from 7400 series ICs](http://blog.notdot.net/2012/10/Build-your-own-FPGA)
  DIY FPGA competition submission and source.
  https://github.com/arachnid/dfpga

- [Libre-SOC](https://libre-soc.org/)
  Open source high performance CPU/GPU/VPU on a chip.
  Focused on high performance open-sourced OpenPOWER architecture

- [F4PGA](https://f4pga.org/)
  Umbrella project based on Yosys for synthesis of code toward an HDL..
  Good place to first learn about toolchains, but some dead links

## Research papers

- [Sunburst design whitepapers](http://www.sunburst-design.com/papers/)
  reference papers on coding standard etc..
  Range of difficulties

## Games

- [NandGame](https://nandgame.com/)
  Browser based puzzle game about logic gates.
  serves as litmus test to determine familiarity with digital logic. Good for visual learners

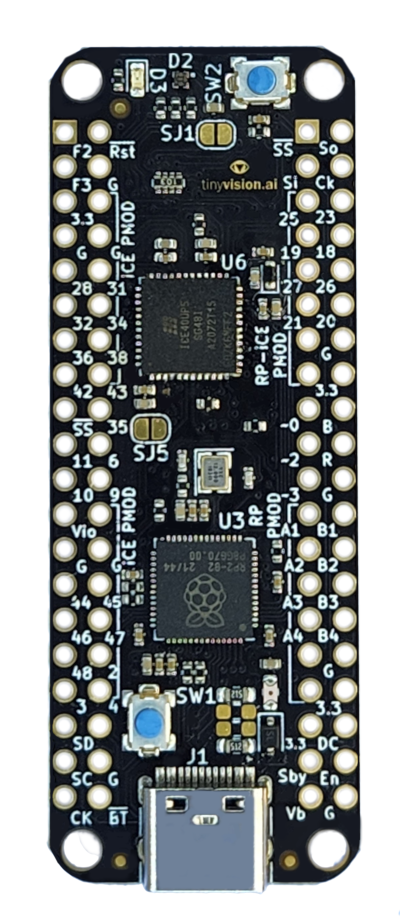
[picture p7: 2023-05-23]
Docs/pinout/pico_ice_front.png

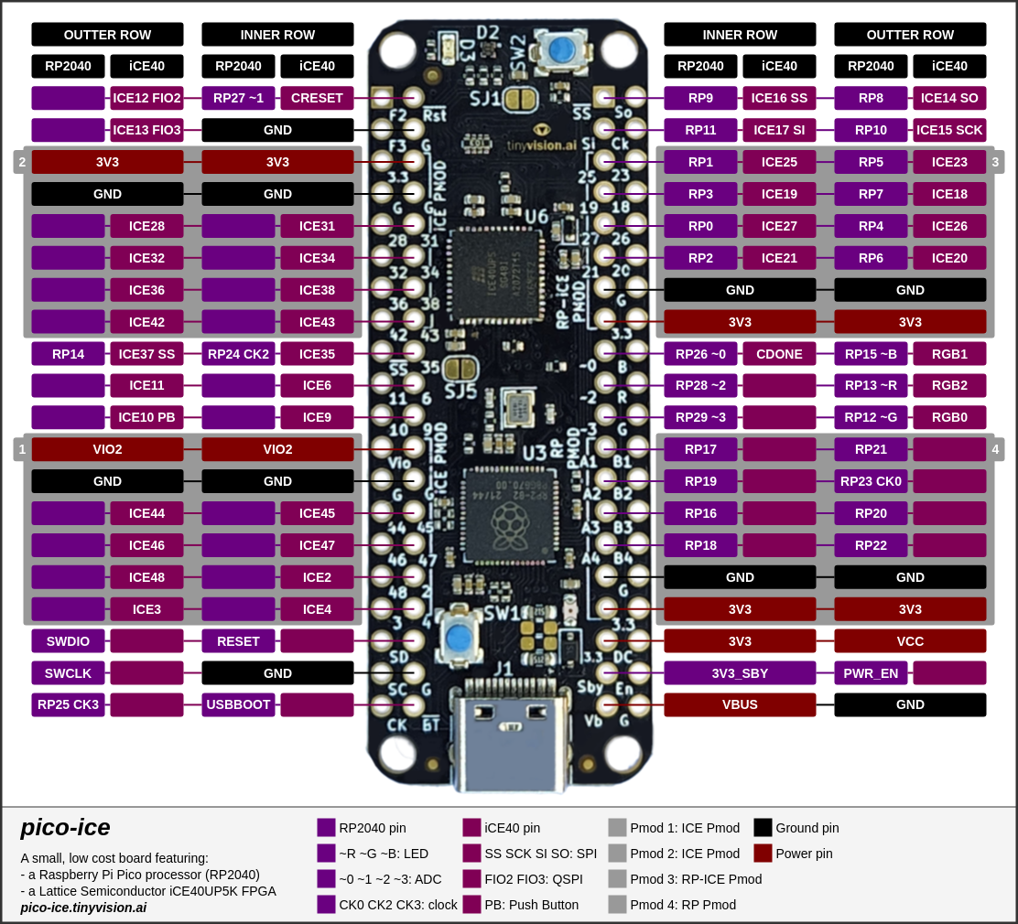
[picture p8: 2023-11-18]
Docs/pinout/pinout.png

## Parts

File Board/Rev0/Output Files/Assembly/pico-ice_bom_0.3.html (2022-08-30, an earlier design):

Source File | pico-ice.kicad_sch
BoM Date | 8/24/2022 4:12:09 PM
Schematic Version | 0.3
Schematic Date | 2020-08-10
PCB Variant | default
KiCad Version | Eeschema (6.0.5)
Component Groups | 26
Component Count (per PCB) | 90
Fitted Components (per PCB) | 90
Number of PCBs | 1
Total Component Count (for 1 PCBs) | 90
 | Description | Part | References | Value | Footprint | Quantity Per PCB | Datasheet | MPN | Manufacturer | Supplier | Digi-Key Part Number | Comment
1 | Unpolarized capacitor | C | C1 C2 | 27p | C_0402_1005Metric | 2 | ~ | GCM1555C1H270JA16D | Murata Electronics | LCSC
2 |  | Device_C | C4 C5 C8 C10 C12 C14 C15 C16 C17 C18 C19 C20 C21 C23 C24 C26 C27 C28 C29 C33 C35 C38 C39 C40 C41 C42 | 0.1u | C_0402_1005Metric | 26 |  | GRM155R71C104KA88J | Murata Electronics | Mouser
3 |  | Device_C | C3 C6 C7 C9 C11 C13 C22 C25 C30 C31 C32 C34 C43 | 4.7u | C_0402_1005Metric | 13 |  | GRM155R60J475ME87D | Murata Electronics | LCSC
4 |  | Diode_1N4148W | D1 | 1N4148WT-7 | D_SOD-523 | 1 | https://www.vishay.com/docs/85748/1n4148w.pdf | 1N4148WT-7 | Micro Commercial Co | LCSC
5 |  | Device_LED_ALT | D3 | LTST-C191KGKT | LED_0603_1608Metric | 1 |  | LTST-C191KGKT | Lite-On | LCSC
6 |  | Device_LED_ARGB | D2 D4 | MHPA1010RGBDT | LED_Cree-PLCC4_1x1mm_CW | 2 |  | MHPA1010RGBDT | MEIHUA | LCSC | LCSC
7 |  | 2x3_2.54mm_Female | J10 J11 | 2x3_2.54mm_Female | PinSocket_2x03_P2.54mm_Horizontal | 2 |  | DW254W-22-06-85 | DEALON | LCSC
8 | Generic connector, double row, 02x06, row letter first pin numbering scheme (pin number consists of a letter for the row and a number for the pin index in this row. a1, ..., aN; b1, ..., bN), script generated (kicad-library-utils/schlib/autogen/connector/) | Conn_02x06_Row_Letter_First | J3 J4 J6 J7 J8 | 6X2 Female Header | PMOD_2x06_P2.54mm_Horizontal | 5 | ~ | DW254W-22-12-85 | DEALON | LCSC |  | PMOD_PICO Dual PMOD A Single PMOD SPARES Dual PMOD B
9 | Generic connector, single row, 01x02, script generated (kicad-library-utils/schlib/autogen/connector/) | Conn_01x02 | J2 J9 | SWD | PinHeader_1x02_P2.54mm_Vertical | 2 | ~ | PZ254V-11-02P | XFCN | LCSC
10 | USB 2.0-only Type-C Receptacle connector | USB_C_Receptacle_USB2.0 | J1 | USB_C_Receptacle_USB2.0 | USB_C_Receptacle_HRO_TYPE-C-31-M-12 | 1 | https://www.usb.org/sites/default/files/documents/usb_type-c.zip | USB4105-GF-A | GCT | Mouser
11 |  | Device_R | PTC1 | MF-FSMF035X-2 | R_0603_1608Metric | 1 | https://www.bourns.com/docs/Product-Datasheets/mffsmf.pdf | MF-FSMF035X-2 | Bourns Inc. | LCSC
12 | Resistor | R | R4 R5 R6 R22 R23 R25 | 27 | R_0402_1005Metric | 6 | ~ | RC0402FR-0727RL | YAGEO | LCSC
13 |  | Device_R | R11 | 100 | R_0402_1005Metric | 1 |  | RC0402FR-07100RL | YAGEO | LCSC
14 | Resistor | R | R1 R2 | 1k | R_0402_1005Metric | 2 | ~ | RC0402FR-071KL | YAGEO | LCSC
15 |  | Device_R | R14 R18 R19 R20 | 2.2K | R_0402_1005Metric | 4 |  | RC0402FR-072K2L | YAGEO | LCSC
16 |  | Device_R | R10 R24 | 5.1K | R_0402_1005Metric | 2 |  | RC0402FR-075K1L | YAGEO | LCSC
17 |  | Device_R | R7 R8 R9 R12 R13 R15 R16 R17 R21 | 10K | R_0402_1005Metric | 9 |  | RC0402FR-0710KL | YAGEO | LCSC
18 | Push button switch, generic, two pins | SW_Push | SW1 | PTS820 J25K SMTR LFS | PTS820J25KSMTRLFS | 1 | ~ | PTS820 J25K SMTR LFS | C&K | Mouser |  | ~RESET
19 | Push button switch, generic, two pins | SW_Push_1 | SW2 | PTS820 J25K SMTR LFS | PTS820J25KSMTRLFS | 1 | ~ | PTS820 J25K SMTR LFS | C&K | Mouser |  | SW_Push
20 |  | W25Q32JVSS-Memory_Flash | U5 | APS6404L-3SQN-SN | SOIC-8_3.9x4.9mm_P1.27mm | 1 | http://www.winbond.com/resource-files/w25q32jv%20revg%2003272018%20plus.pdf | APS6404L-3SQN-SN | AP Memory | Mouser
21 |  | AP2127K-1.2 | U4 | CL9293A12L5M | SOT-23-5 | 1 | https://www.diodes.com/assets/Datasheets/AP2127.pdf | CL9293A12L5M | ChipLink Tech | LCSC
22 |  | ICE40UP5K-SG48ITR-FPGA_Lattice | U6 | ICE40UP5K-SG48ITR | QFN-48-1EP_7x7mm_P0.5mm_EP5.6x5.6mm | 1 | http://www.latticesemi.com/Products/FPGAandCPLD/iCE40Ultra | ICE40UP5K-SG48I | Lattice | Mouser
23 | 1A Low drop-out regulator, Fixed Output 3.3V, SOT-223 | NCP1117-3.3_SOT223 | U1 | NCP1117ST33T3G | SOT-223-3_TabPin2 | 1 | http://www.onsemi.com/pub_link/Collateral/NCP1117-D.PDF | NCP1117ST33T3G | onsemi | LCSC
24 |  | MCU_RaspberryPi_RP2040_RP2040 | U3 | RP2040 | RP2040-QFN-56 | 1 |  | RP2040 | Raspberry Pi | LCSC
25 |  | W25Q32JVSS-Memory_Flash | U2 U8 | W25Q32JVSSIQ | SOIC-8_5.23x5.23mm_P1.27mm | 2 | http://www.winbond.com/resource-files/w25q32jv%20revg%2003272018%20plus.pdf | W25Q32JVSSIQ | Winbond Elec | LCSC
26 | Four pin crystal, GND on pins 2 and 4 | Crystal_GND24 | Y1 | 12 MHz | Crystal_SMD_2520-4Pin_2.5x2.0mm | 1 | ~ | ABM10-166-12.000MHZ-T3 | Abracon LLC | Mouser

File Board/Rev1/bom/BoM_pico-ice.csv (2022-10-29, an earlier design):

Item | Qty | Designator | Value | Comment | MPN | Footprint | Datasheet | Manufacturer
1 | 2 | C1, C2 | 27p | CAP CER 27PF 50V C0G/NP0 0402 | GCM1555C1H270JA16D | Capacitor_SMD:C_0402_1005Metric | ~ | Murata Electronics
2 | 13 | C3, C6, C7, C9, C11, C13, C22, C25, C30, C31, C32, C34, C37 | 4.7u | CAP CER 4.7UF 6.3V X5R 0402 | GRM155R60J475ME87D | Capacitor_SMD:C_0402_1005Metric |  | Murata Electronics
3 | 19 | C4, C5, C8, C10, C12, C15, C16, C17, C18, C19, C21, C24, C26, C27, C28, C29, C33, C36, C42 | 0.1u | CAP CER 0.1UF 16V X7R 0402 | GRM155R71C104KA88J | Capacitor_SMD:C_0402_1005Metric |  | Murata Electronics
4 | 2 | D1, D6 | 1N4148WT-7 | DIODE GEN PURP 80V 125MA SOD523 | 1N4148WT-7 | Diode_SMD:D_SOD-523 | https://www.vishay.com/docs/85748/1n4148w.pdf | Micro Commercial Co
5 | 1 | D2 | MHPA1010RGBDT | Common anode RGB 120Â° SMD,1x1x0.6mm LED | MHPA1010RGBDT | CUSTOM:LED_Cree-PLCC4_1x1mm_CW | ~ | MEIHUA
6 | 1 | D3 | LTST-C191KGKT | LED GREEN CLEAR SMD | LTST-C191KGKT | LED_SMD:LED_0603_1608Metric |  | Lite-On
7 | 2 | D4, D5 | 1N5819WS | 1MA@40V 40V SINGLE 1A 0.6V@1A SOD-323 SCHOTTKY BARRIER DIODES | 1N5819WS | Diode_SMD:D_SOD-323 | ~
8 | 1 | J1 | USB_C_Receptacle_USB2.0 | CONN RCP USB2.0 TYP C 24P SMD RA | USB4105-GF-A | Connector_USB:USB_C_Receptacle_HRO_TYPE-C-31-M-12 | https://www.usb.org/sites/default/files/documents/usb_type-c.zip | GCT
9 | 1 | PTC1 | MF-FSMF035X-2 | PTC RESET FUSE 6V 350MA 0603 | MF-FSMF035X-2 | Resistor_SMD:R_0603_1608Metric | https://www.bourns.com/docs/Product-Datasheets/mffsmf.pdf | Bourns Inc.
10 | 1 | Q1 | 2N7002 | 60V 115MA 7.5?@50MA,5V 200MW N CHANNEL | 2N7002 | Package_TO_SOT_SMD:SOT-23 | https://www.onsemi.com/pub/Collateral/NDS7002A-D.PDF
11 | 6 | R1, R2, R6, R17, R18, R19 | 1k | RES 1K OHM 1% 1/16W 0402 | RC0402FR-071KL | Resistor_SMD:R_0402_1005Metric | ~ | YAGEO
12 | 6 | R4, R5, R9, R12, R23, R25 | 27 | RES 27 OHM 1% 1/16W 0402 | RC0402FR-0727RL | Resistor_SMD:R_0402_1005Metric | ~ | YAGEO
13 | 1 | R7 | 100K | RES 100K OHM 1% 1/16W 0402 | RC0402FR-07100KL | Resistor_SMD:R_0402_1005Metric |  | YAGEO
14 | 4 | R8, R13, R16, R21 | 10K | RES 10K OHM 1% 1/16W 0402 | RC0402FR-0710KL | Resistor_SMD:R_0402_1005Metric |  | YAGEO
15 | 2 | R10, R24 | 5.1K | RES 5.1K OHM 1% 1/16W 0402 | RC0402FR-075K1L | Resistor_SMD:R_0603_1608Metric_Pad0.98x0.95mm_HandSolder |  | YAGEO
16 | 1 | R11 | 100 | RES 100 OHM 1% 1/16W 0402 | RC0402FR-07100RL | Resistor_SMD:R_0402_1005Metric |  | YAGEO
17 | 1 | R14 | 2.2K | RES 2.2K OHM 1% 1/16W 0402 | RC0402FR-072K2L | Resistor_SMD:R_0402_1005Metric |  | YAGEO
18 | 1 | R15 | 5.1K | RES 5.1K OHM 1% 1/16W 0402 | RC0402FR-075K1L | Resistor_SMD:R_0402_1005Metric |  | YAGEO
19 | 1 | RN1 | 10K | RESISTOR THICK FILM ARRAY 10K OHM 5% 1/16W ISOL MOLDED 8-PIN 0804 CONCAVE |  | Resistor_SMD:R_Array_Concave_4x0402 | ~
20 | 2 | SW1, SW2 | PTS820 J25K SMTR LFS | SWITCH TACTILE SPST-NO 0.05A 12V | PTS820 J25K SMTR LFS | CUSTOM:PTS820J25KSMTRLFS | ~ | C&K
21 | 1 | U1 | CL9293A12L5M | IC REG LINEAR 1.2V 300MA SOT23-5 | CL9293A12L5M | Package_TO_SOT_SMD:SOT-23-5 | https://www.diodes.com/assets/Datasheets/AP2127.pdf | ChipLink Tech
22 | 2 | U2, U8 | W25Q32JVSSIQ | IC FLASH 32MBIT SPI/QUAD 8SOIC | W25Q32JVSSIQ | Package_SO:SOIC-8_5.23x5.23mm_P1.27mm | http://www.winbond.com/resource-files/w25q32jv%20revg%2003272018%20plus.pdf | Winbond Elec
23 | 1 | U3 | RP2040 | ARM Cortex-M0 264KB 2 133MHz 30 2 QFN-56(7x7) | RP2040 | RP2040_minimal:RP2040-QFN-56 |  | Raspberry Pi
24 | 1 | U4 | CL9293A33L5M | IC REG LINEAR 1.2V 300MA SOT23-5 | CL9293A12L5M | Package_TO_SOT_SMD:SOT-23-5 | https://www.diodes.com/assets/Datasheets/AP2127.pdf | ChipLink Tech
25 | 1 | U5 | APS6404L-3SQN-SN | DRAM IoT RAM 64Mb SOP8 | APS6404L-3SQN-SN | Package_SO:SOIC-8_3.9x4.9mm_P1.27mm | http://www.winbond.com/resource-files/w25q32jv%20revg%2003272018%20plus.pdf | AP Memory
26 | 1 | U6 | ICE40UP5K-SG48ITR | IC FPGA 39 I/O 48QFN | ICE40UP5K-SG48I | Package_DFN_QFN:QFN-48-1EP_7x7mm_P0.5mm_EP5.6x5.6mm | http://www.latticesemi.com/Products/FPGAandCPLD/iCE40Ultra | Lattice
27 | 1 | Y1 | 12 MHz | CRYSTAL 12.0000MHZ 8PF SMD | ABM10-166-12.000MHZ-T3 | Crystal:Crystal_SMD_2520-4Pin_2.5x2.0mm | ~ | Abracon LLC

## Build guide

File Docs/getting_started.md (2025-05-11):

# Getting Started

Once you receive the board, you would be able to plug via USB and see the RGB LED blinking.
You might want to update the default firmware to make sure to have the latest bugfixes:

## Default Firmware

[source](https://github.com/tinyvision-ai-inc/pico-ice/blob/main/Firmware/pico-ice-default/) -
[download](https://github.com/tinyvision-ai-inc/pico-ice/releases/)

To provide the various USB programming methods and allow to boot the FPGA, a
default firmware is loaded onto the RP2040 (Pico part of the pico-ice).

It provides:

- A first USB-serial (#0) is used for the and a REPL command line interface
  for now only showing help message and version information.

- A second USB-serial (#1) is used for mirroring everything between
  this USB interface UART TX on RP0 with ICE27, UART RX on RP1 with ICE25.

- A third USB-serial (#2) is exchanging data with the main SPI bus onboard
  ([doc](https://pico-ice.tinyvision.ai/ice_usb.html#usb-spi-fpgasramflash-forwarding)).

- A 12 MHz clock is exported from the RP2040 pin 24 toward the iCE40 pin 35.

- An USB DFU interface allows programming through [dfu-utils](https://dfu-util.sourceforge.net/)
  as shipped with [oss-cad-suite](https://github.com/YosysHQ/oss-cad-suite-build).

- An USB MSC interface allows programming the board by copying a file to an USB device
  ([doc](https://pico-ice.tinyvision.ai/programming_the_fpga.html#using-a-drag-drop-or-file-copy-scheme)).

See [Programming the RP2040](md_programming__the__mcu.html) for how to load this firmware file.

## Soldering the Pmods

In case you ordered the board without the [Pmod](md_pmods.html) connectors soldered,
you would need to solder them in to plug something onto the board.
For instance like this:

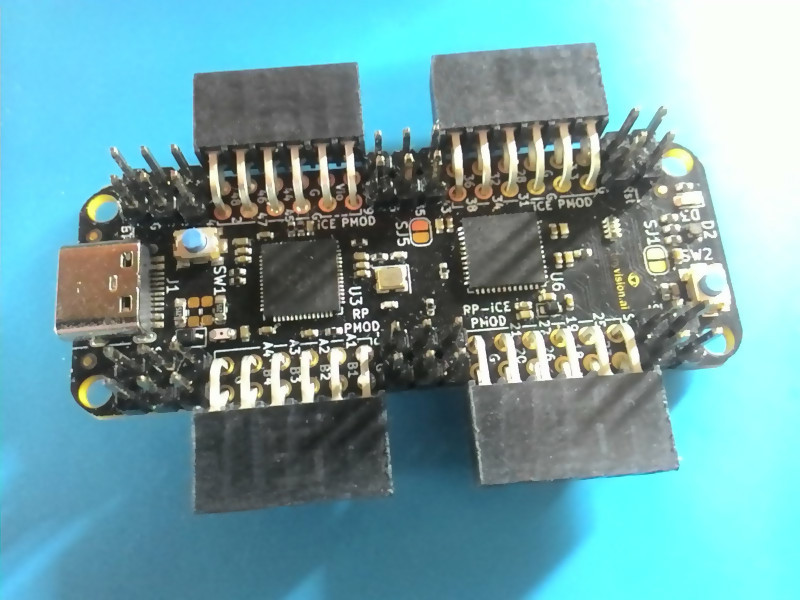
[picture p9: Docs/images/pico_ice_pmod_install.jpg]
pmod install after soldering


## Using the SDK

The [RP2040](https://www.raspberrypi.com/products/rp2040/specifications/) on the
pico-ice can be programmed with either custom C firmware, or languages such as
[MicroPython](https://micropython.org/download/RPI_PICO/),
[CircuitPython](https://circuitpython.org/board/raspberry_pi_pico/),
[Go](https://tinygo.org/docs/reference/microcontrollers/pico/),
[Rust](https://docs.rs/rp2040/latest/rp2040/),
[JavaScript](https://kalumajs.org/),
[ZeptoForth](https://github.com/tabemann/zeptoforth),
[Mecrisp Forth](https://wellys.com/posts/rp2040_forth/),
...

Currently C/C++ programming is best suported through the pico-ice-sdk:
a Raspberry Pi [pico-sdk](https://github.com/raspberrypi/pico-sdk/) library.

This is a guide for how to build application running on the RP2040 microcontroller.

The [pico-ice-sdk](https://github.com/tinyvision-ai-inc/pico-ice-sdk/) provides an API for communicating with the pico-ice hardware, also allowing to use the Raspberry Pi [pico-sdk](https://github.com/raspberrypi/pico-sdk/) directly.

The pico-ice-sdk is organised as a normal pico-sdk project with `pico_ice` custom board.

The [examples](https://github.com/tinyvision-ai-inc/pico-ice-sdk/blob/main/examples/) show how everything can be to get started.

Here is how to turn an example into a new project:

    # copy the whole example directory
    cp -r pico-ice-sdk/examples/pico_usb_uart my-new-pico-ice-firmware
    cd my-new-pico-ice-firmware

    # turn it into a git repository
    git init
    git remote add origin git@github.com:your-username/my-new-pico-ice-firmware

    # replace the two symlinks by git submodules
    rm pico-sdk pico-ice-sdk
    git submodule add https://github.com/raspberrypi/pico-sdk
    git submodule add https://github.com/tinyvision-ai-inc/pico-ice-sdk

    # fetch the submodules (using --recursive is very slow)
    git -C pico-ice-sdk submodule update --init
    git -C pico-sdk submodule update --init lib/tinyusb

    # you can now build it as a CMake project
    mkdir build && cd build
    cmake .. && make

You can now edit the name of the project in the CMakeLists.txt, add new sources, and change the code.

## Troubleshooting

Feel free to join the [chat server](https://discord.gg/sb2kwc66) to ask for help.

### Using some RP2040 peripheral cause various bugs.

In order to power the FPGA, some peripherals and GPIO pins are in use by the pico-ice-sdk.
In case both the firmware and SDK use the same peripheral, it is possible to use another free peripheral instance, or if none left, disable the feature of the SDK
The `ice_init()` is responsible for setting-up all peripherals used by the SDK.
Instead, calling manually each `ice_init_<feature>()` of interest permits to select what to enable or not in the board, and therefore keeping some more peripherals for the user.

### Error: C++ compiler not installed on this system

The pico-sdk is written in C, but uses a single C++ file to enable C++ support in the SDK.
This means you need a working C++ cross compiler, often named `arm-none-eabi-g++`.

Even if this binary is present in your system, it might not be a full C++ installation.
If you do not need C++ and want to work around this bug, you can disable the C++ support
in the pico-sdk. From your project repo:

    $ cd build
    $ cmake .. # download the SDK if not yet done
    $ sed -i '/new_delete.cpp/ d' _deps/pico-sdk-src/src/rp2_common/pico_standard_link/CMakeLists.txt
    $ cmake .. # rebuild the Makefile with the fix

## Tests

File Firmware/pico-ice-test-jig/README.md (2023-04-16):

# Automated Testing of the pico-ice

This firmware is meant for testing all connections of the board with a rig as described below.

## Test process

1. load the firmware.uf2 onto the RP2040 (drag-and-drop)
2. load the bitstream.bin onto the iCE40 (dfu-util)
3. reset the board (SW1)
4. press the button to start the test outside of the jig (SW2), it should turn blue
5. put the board onto the jig
6. press the button to start the test inside of the jig (SW2), it should turn green
7. at the end, to ease debugging, the FPGA is still programmable, and a square wave
   of 10 Hz is sent through the whole chain, which permits to observe where it
   eventually stops.

## Color code

- GREEN boards passed the test, can be loaded with a blinky.
- RED boards need troubleshooting, and USB UART has the full log detail
- BLINKING boards are ready to be packaged and shipped.

## Test jig

- There are horizontal (`─`) physical connections made with wires, except around `ICE_12` and `ICE_13` that are instead connected with each other vertically (`│`).
- The vertical connections (`:`) and long connections (`....`) are made internally by the FPGA.

Together, these connecitons are building a test chain on the FPGA, whose input is controlled by the RP2040 which performs tests and report with the LED color.

```
    ┌────────────────────────────────┐
    │                                │
    │                                │
    │   ......................       │
    │ .'                      '.     │
ICE_12█   █              ICE_16█───█ICE_14
    │ │                            : │
ICE_13█   █              ICE_17█───█ICE_15
    ├──:────┐                ┌─:─────┤
    │ █:  █ │            ICE_25█───█ICE_23
    │  :    │                │     : │
    │ █:  █ │            ICE_19█───█ICE_18
    │  :    │                │ :     │
ICE_28█───█ICE_31     <--ICE_27█   █ICE_26<--
    │     : │                │    .' │
ICE_32█───█ICE_34    btn/ICE_21█.' █ICE_20/high-z
    │ :     │                │.'     │
ICE_36█───█ICE_38           .' █   █ │
    │     : │             .' │       │
ICE_42█───█ICE_43       .'   │ █   █ │
    ├─:─────┘         .'     └───────┤
ICE_37█───█ICE_35   .'   GPIO26█───█GPIO15
    │     :        :                 │
ICE_11█───█ICE_6   :     GPIO28█───█GPIO13
    │ :            :                 │
ICE_10█───█ICE_9   :     GPIO29█───█GPIO12
 PB ├────:──┐      :         ┌───────┤
    │ █  :█ │      :     GPIO16█───█GPIO20
    │    :  │      :         │       │
    │ █  :█ │      :     GPIO17█───█GPIO21
    │    :  │      :         │       │
ICE_44█───█ICE_45  :     GPIO18█───█GPIO22
    │ :     │      :         │       │
ICE_46█───█ICE_47  :     GPIO19█───█GPIO23
    │     : │      :         │       │
ICE_48█───█ICE_2   :         │ █   █ │
    │ :     │    .'          │       │
 ICE_3█───█ICE_4'            │ █   █ │
    ├───────┘                └───────┤
 SWDIO█   █                    █   █ │
    │                                │
 SWCLK█   █                    █   █ │
    │          ││||||||||││          │
GPIO25█   █   O            O   █   █ │
    │         │            │         │
    │         │            │         │
    │         o            o         │
    │         │            │         │
    └─────────┴────────────┴─────────┘
```

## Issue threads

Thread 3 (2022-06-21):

Add the full ICE qSPI signals to the PICO

vr2045, 2022-06-21:
So the request is to add the full qSPI to the ICE flash to the RPi as well so it can be used to program/read the ICE flash faster. I think this makes sense. Given that we wont be running this interface very fast anyway, this should work out.

_Originally posted by @vr2045 in https://github.com/tinyvision-ai-inc/pico-ice/discussions/2#discussioncomment-2989632_

vr2045, 2022-06-25:
We're out of pins on the PICO. Adding the 2 qSPI signals to the RP would be nice to have but would mean that we lose some functionality. Currently have a dedicated 8 bit bus as well as a single dual PMOD from the PICO, RGB LED, FPGA programming control and a couple of ADC channels.
I dont see how we can support this so closing the issue.

Closed 2022-06-25.

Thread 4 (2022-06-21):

Fix clock output pin from PICO

vr2045, 2022-06-21:
Pins supporting clock output:

* GPIO21 (currently ICE_DONE),
* GPIO23 (currently PICO_23_MOSI0),
* GPIO24 (currently PICO_24_MISO0),
* GPIO25 (currently PICO_25_SSn0)

The GPIO21 seems the easiest to move in case we want to use a variable speed PLL from the RP2040.

_Originally posted by @josuah in https://github.com/tinyvision-ai-inc/pico-ice/discussions/2#discussioncomment-2985223_

vr2045, 2022-06-25:
Done, we have 2 clocks coming from the RP now: one for the FPGA and the other for the peripheral header.

Closed 2022-06-25.

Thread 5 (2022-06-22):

Document "RGB pin low = turned on" for PR2040

josuah, 2022-06-22:
**RGB LED direction:**
is it common to have the LEDs (D2, D4) oriented in that direction? It would mean having to set a pin down to turn the led on.

At least on the raspberry pico board, it is the opposite for the on-board LED.

_Originally posted by @josuah in https://github.com/tinyvision-ai-inc/pico-ice/discussions/2#discussioncomment-2984908_

Closed 2022-08-27.

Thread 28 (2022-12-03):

Support this board in ICEStudio

benitoss, 2022-12-03:
I would like to contribute to this proyect giving support to this board in ICEStudio.
I have already experience because I added the ColorBoard FPGAs (ECP) in IceStudio and Appio
Please contact with me for more details

Fernando Mosquera (benitoss@gmail.com)

josuah, 2022-12-14:
Apologies for the long delay! I only noticed this now. Will come back to you shortly, if the proposition still holds of course...
Note, I am not the project main author, but do a lot of house cleaning.

vr2045, 2022-12-14:
Sure, that would be great! I'll email you...

benitoss, 2023-01-21:
The board is already supported by IceStudio/Apio

Closed 2023-01-21.

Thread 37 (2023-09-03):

PMOD numbering mismatch in pinout diagram

gumpu, 2023-09-03:
In the legenda of the  pinout diagram   https://github.com/tinyvision-ai-inc/pico-ice/blob/main/Docs/pinout/pinout.svg
it says that:  PMOD 3 is a "RP PMOD" and PMOD 4 is a "RP-ICE PMOD".

However the diagram itself seems to indicate the opposite; The gray box labeled 4 contains only RP labels, while the box labeled 3 contains both RP and ICE labels.

josuah, 2023-09-03:
Fixed by https://github.com/tinyvision-ai-inc/pico-ice/commit/99993c1379a183c67c775891324ef615c6d16f75

Thank you for reporting!

Thanks to https://pinout.readthedocs.io/en/latest/ for allowing this to be a 2-line patch!

Closed 2023-09-03.

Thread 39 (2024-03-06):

Board can't run fpga flash after reboot

vanbwodonk, 2024-03-06:
Hi, I have bought 2pcs pico-ice from elecrow. However, 1 board cannot run FPGA programs from flash. I flashed using dfu-util, using pico-ice-default version 1.5. FPGA runs normally after flashing, but if the USB power is turned off and then turned on again. FPGAs can't run from flash.

It's not a problem for me to check the flash chip/replace it. Is there a way to ensure that the flash chip (winbond) is truly damaged?

josuah, 2024-03-06:
Hello! Thank you for getting in touch. There could be other reasons such as a problem in the firmware that make the FPGA go in halt mode, such as when the UF2 programming interface is read by the OS: the `pico-ice` storage device... or other quirks.

One way to test would be this small example that writes to the flash and read the result back (use test.py to see how to test for instance):
https://github.com/tinyvision-ai-inc/pico-ice-sdk/tree/main/examples/pico_flash

Another way would be trying this other example as it contains the DFU prorammer in addition to the UART interface:
https://github.com/tinyvision-ai-inc/pico-ice-sdk/tree/main/examples/pico_usb_uart

I did find an error while programming to flash using DFU-util using that hexample though:
```
Download        [                         ]   0%            0 bytesdfu-util: Error during download get_status (LIBUSB_ERROR_PIPE)
```

I will investigate the bug and it will be fixed as part of the upcoming v1.6 default firmware and SDK release...
It is also possible to try the UF2 programming method in hope that this gives more luck:
https://pico-ice.tinyvision.ai/md_programming_the_fpga.html#autotoc_md34

josuah, 2024-03-15:
It might be interesting to try this again after https://github.com/tinyvision-ai-inc/pico-ice-sdk/pull/51 gets merged.

vanbwodonk, 2024-03-16:
Thank you. My pico-ice is in the office, i will try it on Monday.

vanbwodonk, 2024-03-19:
Tried this  [PR](https://github.com/danieldegrasse/pico-ice-sdk/tree/fix/usb-dfu-flashwrite), and it works. I hope this will be merged soon.

This problem occurred because I flashed the FPGA firmware in CRAM, because I read the old code when the Flash was DFU+1. But still pico-ice-default version 1.5 can't dfu-util flash area with this error:

> Download        [                         ]   0%            0 bytesdfu-util: Error during download get_status (LIBUSB_ERROR_PIPE)

josuah, 2024-03-19:
There is definitely some problem with the firmware. In about a month, I will be given some time to come back to all the pico-ice issues.

I will try to get something going by then to fix the pain-points. Hopefully this will be included.

josuah, 2024-04-20:
I only completed the review now. This is now merged and a new release is being prepared.
Thank you all for this collaborative review and improvements!
A new release is pending.
Feel free to reopen if anything is missing.

Closed 2024-04-20.

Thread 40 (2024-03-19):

[REQUEST] USB CDC detect line_coding & Arduino like reboot detection

vanbwodonk, 2024-03-19:
I modified pico_ice_default and pico-ice-sdk/examples/pico_usb_uart with line_coding detection and 1200 bitrate detection for autoreboot. This is very useful if we need a higher bitrate than 115200, and Arduino like auto-reboots when we need to reflash the RP2040. Just need to add some code like this:
```
void tud_cdc_line_coding_cb(uint8_t itf, cdc_line_coding_t const *coding) {
  if (itf == 0) {
    if (coding->bit_rate != baud_rate) {
      baud_rate = coding->bit_rate;
      uart_set_baudrate(uart0, baud_rate);
    }
  }
}

void tud_cdc_line_state_cb(uint8_t itf, bool dtr, bool rts) {
  if (itf == 0) {
    if (rts) {
    }
    if (dtr) {
    } else {
        cdc_line_coding_t coding;
        tud_cdc_get_line_coding(&coding);
        if (coding.bit_rate == 1200) {
          reset_usb_boot(0, 0);
          while (1);
        }
    }
  }
}
```

Or, if you allow I can make a PR about it.

josuah, 2024-03-19:
Thank you for this! The way it is implemented makes sense to me, and easy to make that configurable with just an `#ifdef` and [a config in `tusb_config.h`](https://pico-ice.tinyvision.ai/group__ice__usb.html).

josuah, 2024-04-17:
I am now back from Embedded World and will be able to switch over to integrating this, likely tomorrow.
Thanks everyone for your patience!

josuah, 2024-04-20:
Adjusting the baud rate works well with what you provided.
I edited it a tiny bit for matching the autoconfig.

Before, baud 1200
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

After, baud 4800 (mismatching Pulseview configuration)
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

MrJake222, 2024-04-20:
Nice! Does it support resetting and programming with `picotool` (`-f` option)?

josuah, 2024-04-20:
> Does it support resetting and programming with `picotool` (`-f` option)?

Not yet, but https://arduino.github.io/arduino-cli/dev/platform-specification/#1200-bps-bootloader-reset will be supported

josuah, 2024-04-20:
I confirm that after using `picocom -b 1200 /dev/ttyACM0` it is possible to use `picotool` though:

```
$ picotool info
Program Information
 name:      pico_ice_default
 features:  USB stdin / stdout
```

josuah, 2024-04-20:
This landed in v1.6.1, closing :)

MrJake222, 2024-04-20:
Great! I think you only forgot to create new github release with binaries to download

josuah, 2024-04-21:
It was in preparation at that moment, and landed here: https://github.com/tinyvision-ai-inc/pico-ice/releases

MrJake222, 2024-05-11:
> This landed in v1.6.1, closing :)

Did it? Can confirm it works in downloaded `.uf2` but I cannot find any commits or code to build it myself.... Am i blind or you didn't push something?

josuah, 2024-05-11:
Good catch!

As seen here, `main` was not pushed to `origin/main`, only `develop` to `origin/develop`
```
* 8d0fd06 (HEAD -> develop, tag: v1.6.1, origin/develop, main) implement tud_cdc_line_coding_cb
* 8e92021 (tag: v1.6.0, origin/main, origin/HEAD) stop ICE40 FPGA before initializing SPI flash
```

I pushed it now: https://github.com/tinyvision-ai-inc/pico-ice-sdk/blob/main/src/ice_usb.c#L317

Closed 2024-04-20.

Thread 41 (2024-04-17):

Firmware version v1.5.1 can't write to flash (cram works ok)

MrJake222, 2024-04-17:
```
$ dfu-util -l                       
dfu-util 0.11

Copyright 2005-2009 Weston Schmidt, Harald Welte and OpenMoko Inc.
Copyright 2010-2021 Tormod Volden and Stefan Schmidt
This program is Free Software and has ABSOLUTELY NO WARRANTY
Please report bugs to http://sourceforge.net/p/dfu-util/tickets/

Found DFU: [1209:b1c0] ver=0100, devnum=57, cfg=1, intf=7, path="1-4", alt=1, name="iCE40 DFU (CRAM)", serial="DE6268F24F3D6C21"
Found DFU: [1209:b1c0] ver=0100, devnum=57, cfg=1, intf=7, path="1-4", alt=0, name="iCE40 DFU (Flash)", serial="DE6268F24F3D6C21"
```

```
$ dfu-util -d 1209:b1c0 -a 1 -D hardware.bin
dfu-util 0.11

Copyright 2005-2009 Weston Schmidt, Harald Welte and OpenMoko Inc.
Copyright 2010-2021 Tormod Volden and Stefan Schmidt
This program is Free Software and has ABSOLUTELY NO WARRANTY
Please report bugs to http://sourceforge.net/p/dfu-util/tickets/

dfu-util: Warning: Invalid DFU suffix signature
dfu-util: A valid DFU suffix will be required in a future dfu-util release
Opening DFU capable USB device...
Device ID 1209:b1c0
Run-Time device DFU version 0101
Claiming USB DFU Interface...
Setting Alternate Interface #1 ...
Determining device status...
DFU state(2) = dfuIDLE, status(0) = No error condition is present
DFU mode device DFU version 0101
Device returned transfer size 256
Copying data from PC to DFU device
Download        [=========================] 100%       104090 bytes
Download done.
DFU state(7) = dfuMANIFEST, status(0) = No error condition is present
DFU state(8) = dfuMANIFEST-WAIT-RESET, status(0) = No error condition is present
Resetting USB to switch back to runtime mode
Done!
```
```
$ dfu-util -d 1209:b1c0 -a 0 -D hardware.bin
dfu-util 0.11

Copyright 2005-2009 Weston Schmidt, Harald Welte and OpenMoko Inc.
Copyright 2010-2021 Tormod Volden and Stefan Schmidt
This program is Free Software and has ABSOLUTELY NO WARRANTY
Please report bugs to http://sourceforge.net/p/dfu-util/tickets/

dfu-util: Warning: Invalid DFU suffix signature
dfu-util: A valid DFU suffix will be required in a future dfu-util release
Opening DFU capable USB device...
Device ID 1209:b1c0
Run-Time device DFU version 0101
Claiming USB DFU Interface...
Setting Alternate Interface #0 ...
Determining device status...
DFU state(2) = dfuIDLE, status(0) = No error condition is present
DFU mode device DFU version 0101
Device returned transfer size 256
Copying data from PC to DFU device
Download        [                         ]   0%            0 bytesdfu-util: Error during download get_status (LIBUSB_ERROR_IO)
```

In version 1.3 flash writing seems to work.

MrJake222, 2024-04-17:
This is fixed by https://github.com/tinyvision-ai-inc/pico-ice-sdk/pull/51

josuah, 2024-04-20:
This was further merged in. Thank you for the detailed report. Will release soon with a few extra other fixes in 1.6.1

Closed 2024-04-20.

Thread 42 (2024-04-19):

10ms/byte delay when dealing with ACM1

MrJake222, 2024-04-19:
**moved from pico-ice-sdk**

Hi,

I'm sending/receiving 2-byte frames to/from iCE40 via `ACM1` virtual serial port. The `serial.read` function always stalls for 20ms. I think it's related to the SDK (not Python or kernel) because `ACM0` doesn't have this delay.

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

# Resolution
Turns out waiting for user input in main loop is not the best strategy.
https://github.com/tinyvision-ai-inc/pico-ice/blob/f9bd6e648ee60ef808dcea329a99da570e69a52e/Firmware/pico-ice-default/main.c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
 That's not how this works. ```getchar_timeout_us``` calls ```stdio_get_until``` which [waits internally](https://github.com/raspberrypi/pico-sdk/blob/6a7db34ff63345a7badec79ebea3aaef1712f374/src/rp2_common/pico_stdio/stdio.c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)!

josuah, 2024-04-20:
Thank you, great insight about `stdio_get_until` busy looping in the "driver"/"hal"/"sdk" code!

Closed 2024-04-20.

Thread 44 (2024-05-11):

Is UART1 tested and working?

MrJake222, 2024-05-11:
UART0 is initialized only here: https://github.com/tinyvision-ai-inc/pico-ice/blob/829b9eceeec39da301c08c93d8ef4ce66aaa2dee/Firmware/pico-ice-default/main.c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
I can't seem to find equivalent lines for UART1 and the pins should be different.

josuah, 2024-05-11:
Hello!  I think the reason for only UART0 being enabled is that this is the only one piped to the FPGA by default:

https://github.com/tinyvision-ai-inc/pico-ice/blob/829b9eceeec39da301c08c93d8ef4ce66aaa2dee/Firmware/pico-ice-default/tusb_config.h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

The several "USB-UART" interfaces presented here: https://pico-ice.tinyvision.ai/md_getting_started.html#autotoc_md6
Are not actually connected to UARTs. I should update the doc to avoid confusion and be more correct.

They are instead bound to different features as described.
In hope I understood your question well, feel free to ask again if I missed something!

MrJake222, 2024-05-11:
I understand that they're only virutal uarts.

My question is, if i define `ICE_USB_UART1_CDC` to `1`, what will happen? will it work? do i get 2 uarts to fpga?

josuah, 2024-05-11:
> if i define ICE_USB_UART1_CDC to 1, what will happen? will it work? do i get 2 uarts to fpga?

As you guessed, you would not, and modifying the firmware would be necessary.

`pico-ice-sdk` is here to enable to quickly put together a firmware that can be used with the FPGA.
It is aimed to be modified at compile time, i.e. with macros.
It contains examples which acts a bit like reference implementations.

`pico-ice-default` is here to provide most of the SDK features in a ready-to-use way.
I have not thought at bringing configuration for it before.
Would an example in `pico-ice-sdk/examples` with dual UART interfaces enabled work for you?
That would avoid adding code that is disabled by default.
Was there other features that you wanted enabled? Such as the USB-serial to SPI interface?

MrJake222, 2024-05-11:
>  Was there other features that you wanted enabled? Such as the USB-serial to SPI interface?

I've disabled SPI-CDC and enabled UART1

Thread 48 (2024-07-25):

pico-ice & pico-ice-sdk

develone, 2024-07-25:
testing pico-ice-sdk & pico-ice
Below are the steps I am using to test pico-ice-sdk & pico-ice
Trying to follow the steps found in pico-ice/Docs/pico_ice_sdk.md

git clone https://github.com/develone/pico-ice-sdk.git -b test-dev

git clone https://github.com/develone/pico-ice.git -b test-dev

cd pico-ice

cp -r ~/pico-ice-sdk/examples/pico_usb_uart my-new-pico-ice-firmware

cd my-new-pico-ice-firmware

rm -rf pico-ice-sdk pico-sdk

git clone https://github.com/tinyvision-ai-inc/pico-ice-sdk

git clone https://github.com/develone/pico-sdk.git

cd pico-sdk

git submodule update --init

Submodule 'lib/btstack' (https://github.com/bluekitchen/btstack.git) registered for path 'lib/btstack'
Submodule 'lib/cyw43-driver' (https://github.com/georgerobotics/cyw43-driver.git) registered for path 'lib/cyw43-driver'
Submodule 'lib/lwip' (https://github.com/lwip-tcpip/lwip.git) registered for path 'lib/lwip'
Submodule 'lib/mbedtls' (https://github.com/Mbed-TLS/mbedtls.git) registered for path 'lib/mbedtls'
Submodule 'tinyusb' (https://github.com/hathach/tinyusb.git) registered for path 'lib/tinyusb'
Cloning into '/home/devel/pico-ice/my-new-pico-ice-firmware/pico-sdk/lib/btstack'...
Cloning into '/home/devel/pico-ice/my-new-pico-ice-firmware/pico-sdk/lib/cyw43-driver'...
Cloning into '/home/devel/pico-ice/my-new-pico-ice-firmware/pico-sdk/lib/lwip'...
Cloning into '/home/devel/pico-ice/my-new-pico-ice-firmware/pico-sdk/lib/mbedtls'...
Cloning into '/home/devel/pico-ice/my-new-pico-ice-firmware/pico-sdk/lib/tinyusb'...
Submodule path 'lib/btstack': checked out '72ef1732c954d938091467961e41f4aa9b976b34'
Submodule path 'lib/cyw43-driver': checked out '8ef38a6d32c54f850bff8f189bdca19ded33792a'
Submodule path 'lib/lwip': checked out '239918ccc173cb2c2a62f41a40fd893f57faf1d6'
Submodule path 'lib/mbedtls': checked out 'a77287f8fa6b76f74984121fdafc8563147435c8'
Submodule path 'lib/tinyusb': checked out '86c416d4c0fb38432460b3e11b08b9de76941bf5'

cd ../

mkdir build

cd build

devel@pi5-80:~/pico-ice/my-new-pico-ice-firmware/build $ cmake ..
PICO_SDK_PATH is /home/devel/pico-ice/my-new-pico-ice-firmware/pico-sdk
Defaulting PICO_PLATFORM to rp2040 since not specified.
Defaulting PICO platform compiler to pico_arm_gcc since not specified.
-- Defaulting build type to 'Release' since not specified.
PICO compiler is pico_arm_gcc
-- The C compiler identification is GNU 12.2.1
-- The CXX compiler identification is GNU 12.2.1
-- The ASM compiler identification is GNU
-- Found assembler: /usr/bin/arm-none-eabi-gcc
-- Detecting C compiler ABI info
-- Detecting C compiler ABI info - done
-- Check for working C compiler: /usr/bin/arm-none-eabi-gcc - skipped
-- Detecting C compile features
-- Detecting C compile features - done
-- Detecting CXX compiler ABI info
-- Detecting CXX compiler ABI info - done
-- Check for working CXX compiler: /usr/bin/arm-none-eabi-g++ - skipped
-- Detecting CXX compile features
-- Detecting CXX compile features - done
Build type is Release
Defaulting PICO target board to pico since not specified.
Using board configuration from /home/devel/pico-ice/my-new-pico-ice-firmware/pico-sdk/src/boards/include/boards/pico.h
-- Found Python3: /usr/bin/python3 (found version "3.11.2") found components: Interpreter
TinyUSB available at /home/devel/pico-ice/my-new-pico-ice-firmware/pico-sdk/lib/tinyusb/src/portable/raspberrypi/rp2040; enabling build support for USB.
BTstack available at /home/devel/pico-ice/my-new-pico-ice-firmware/pico-sdk/lib/btstack
cyw43-driver available at /home/devel/pico-ice/my-new-pico-ice-firmware/pico-sdk/lib/cyw43-driver
Pico W Bluetooth build support available.
lwIP available at /home/devel/pico-ice/my-new-pico-ice-firmware/pico-sdk/lib/lwip
mbedtls available at /home/devel/pico-ice/my-new-pico-ice-firmware/pico-sdk/lib/mbedtls
-- Configuring done
-- Generating done
-- Build files have been written to: /home/devel/pico-ice/my-new-pico-ice-firmware/build

make

[ 74%] Building C object CMakeFiles/pico_usb_uart.dir/pico-sdk/src/rp2_common/pico_stdio_uart/stdio_uart.c.obj
[ 74%] Building C object CMakeFiles/pico_usb_uart.dir/pico-ice-sdk/src/ice_usb.c.obj
/home/devel/pico-ice/my-new-pico-ice-firmware/pico-ice-sdk/src/ice_usb.c:49:10: fatal error: uf2.h: No such file or directory
   49 | #include "uf2.h"
      |          ^~~~~~~
compilation terminated.
make[2]: *** [CMakeFiles/pico_usb_uart.dir/build.make:877: CMakeFiles/pico_usb_uart.dir/pico-ice-sdk/src/ice_usb.c.obj] Error 1
make[1]: *** [CMakeFiles/Makefile2:1528: CMakeFiles/pico_usb_uart.dir/all] Error 2
make: *** [Makefile:91: all] Error 2

develone, 2024-07-25:
tested on Raspberry Pi5 running Raspberry OS 64 bit.
Also tested on Windows 10 in Windows Subsystem for Linux WSL.
Need to be able to compile the pico-ice-sdk before purchasing a pico-ice board.

develone, 2024-07-26:
devel@pi5-80:~/pico-ice-sdk/examples/ice_makefile_blinky $ export OSS_CAD_SUITE=/usr/local
devel@pi5-80:~/pico-ice-sdk/examples/ice_makefile_blinky $ make -f Makefile
/usr/local/bin/yosys -q -p "read_verilog -sv top.sv; synth_ice40 -top top -json gateware.json"
/usr/local/bin/nextpnr-ice40 -q --randomize-seed --up5k --package sg48 --pcf ice40.pcf --json gateware.json --asc gateware.asc
/usr/local/bin/icepack gateware.asc gateware.bin

josuah, 2024-07-26:
Hello! It looks like this requires some `git submodule update --init` inside the `pico-ice-sdk` repo.
Could you try this and confirm it still has the same error?

josuah, 2024-07-26:
This is where the tinyUF2 library is expected to be, and it contains `uf2.h`:
https://github.com/develone/pico-ice-sdk/tree/main/lib

josuah, 2024-07-26:
Looking again, I cannot find the `pico_ice_sdk.md` file. Maybe it is out of date?
I think this latest doc might work better for you: https://pico-ice.tinyvision.ai/md_getting_started.html

develone, 2024-07-28:
Was this code developed in Micosoft Windows? Could this be the issue?

develone, 2024-07-28:
uf2.h & board_api have comments to Microsoft. If you add uf2.h to pico-ice-sdk/include you get the missing board_api.h.

josuah, 2024-07-28:
Sorry I had limited time 2 days ago.

> Was this code developed in Microsoft Windows?

It was developed under Linux (Alpine) and tested on Linux (Ubuntu) on WSL, MinGW from Yosys (for the RTL part at least), and Mac OS by users.

> uf2.h & board_api have comments to Microsoft

UF2 is a format invented by Microsoft to work around the fact that custom USB devices are difficult to use for users, as it requires manually selecting a driver such as WinUSB or libusbK using tools like Zadig.
For this reason, Microsoft developed the UF2 format that permits an USB device to be recognized as a storage device with a FAT32 file system, accepting files uploads of files in the UF2 format. https://github.com/microsoft/uf2

It is a bit of a hack, but permits to do firmware upgrade without installing drivers manually on Windows, and without changing permission issues on most systems. Only a drag-and-drop of a file in the UF2 format.

This is one of the several upload protocols supported by the pico-ice, along with DFU (the standard defined by USB.org which requires some workarounds on Windows but works well via the `dfu-utils` on Linux/MacOSX):
https://pico-ice.tinyvision.ai/md_programming_the_fpga.html

In order to support it for the pico-ice, we picked the TinyUF2 library by Adafruit:
https://github.com/adafruit/tinyuf2

This needs to be populated in this directory in order to provide all the UF2 implementation used for supporting firmware upload through drag-and-drop:
https://github.com/tinyvision-ai-inc/pico-ice-sdk/tree/main/lib

## TL;DR:

Which means that if you run `ls pico-ice-sdk/lib/tinyuf2/`, you should see this:
```
$ ls pico-ice-sdk/lib/tinyuf2/
LICENSE  README.md  apps  changelog.md  cmake  lib  ports  src
```

If you do not, this means a submodule is missing. You might have outdated documentation, and can start over from instructions here: https://pico-ice.tinyvision.ai/md_getting_started.html#autotoc_md8

Or only try this line to fix your ongoing directory.

```
git -C pico-ice-sdk submodule update --init
```

If you have all some files listed as above, this means that maybe something else went wrong. You might need to delete the `build` directory and start over.

develone, 2024-07-29:
Hello! It looks like this requires some git submodule update --init inside the pico-ice-sdk repo.
This appears to be the fix.
steps found https://github.com/develone/pico-ice/blob/test-dev/myDocs/notes-pico-ice-2.txt
All the files in build folder https://github.com/develone/pico-ice/blob/test-dev/myDocs/built-files.txt
Thanks now I can purchase the pico-ice knowing that my learning curve will be reduce.
Please take a look at this pdf.  Adding a file system and FreeRtos might add some enhanced features.

develone, 2024-07-29:
I have been working with the ice40 HX8K using zipcpu.
https://github.com/develone/rp2040-freertos-project/blob/dev/doc/pico-test-read.pdf
https://github.com/develone/102121icozip/blob/catzip/doc/dwt3lvls050924.png

josuah, 2024-07-29:
Glad it ended-up working! That is an interesting project you have. A good improvement over https://github.com/mcknly/breadboard-os

Note that `pico-ice/Docs/pico_ice_sdk.md` disappeared 7 month ago: the documentation got updated.
You will be able to get the latest documentation by doing a `git pull` inside `pico-ice`.

develone, 2024-07-29:
Where is the best place to order a pico-ice board tindie or the tinyvision store?

develone, 2024-07-29:
I ordered 2 pico-ice boards Order #484119 Receipt at Tindie.   I might be looking to some more for students at UTEP here in El Paso, Texas.  Do you have pricing for students.

josuah, 2024-07-29:
Hello and sorry for the delay. Here is the recommendation from who runs tinyVision.ai:
- Lectron-Z for EU and UK mostly (helps with taxes)
- Tindie/tinyVision.ai for US mostly (ships from here)
- Elecrow for all (including EU/UK/US, ships internationally).
I will ask about student/bulk pricing and let you know!

josuah, 2024-07-29:
For this you would need to reach out via one of these ways:
https://tinyvision.ai/pages/contact-us
https://discord.gg/t2CzbAYeD2

josuah, 2024-07-29:
I am closing the issue as the original problem was solved, but no problem with discussing more!

Closed 2024-07-29.

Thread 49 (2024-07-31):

Missing files at repo or did get moved?

develone, 2024-07-31:
I forked both pico-ice and pico-ice-sdk on 07/25/24.
At this time I created branches test-dev in both pico-ice and pico-ice-sdk.

pico-ice
commit 12eea8225a31b25d940c23973c7ff457b6d6097a (origin/main, origin/HEAD)
Author: Josuah Demangeon <me@josuah.net>
Date:   Fri May 26 00:58:02 2023 +0200

pico-ice-sdk
commit 4ebe348ffcb4feb3e2756d101f594679eb02d97c (HEAD -> test-dev, origin/test-dev, origin/main, origin/HEAD)
Author: Josuah Demangeon <me@josuah.net>
Date:   Thu Jun 20 23:12:41 2024 +0200

    examples: ice_makefile_blinky: allow blinking with R, G or B easily

On 07/30/24 I noticed This branch is 88 commits behind tinyvision-ai-inc/pico-ice:main.
pico-ice/Docs
_config.yml         ice_flash.md  images           pinout.md
favicon.ico         ice_fpga.md   index.md         pmods.md
Gemfile             ice_led.md    learn.md         programming_the_fpga.md
Gemfile.lock        ice_spi.md    LICENSE          programming_the_mcu.md
getting_started.md  ice_sram.md   pico_ice_sdk.md
ice_cram.md         ice_usb.md    pinout

Now pico-ice/Docs
Doxyfile             images     pmods.md
doxygen-awesome-css  index.md   programming_the_fpga.md
DoxygenLayout.xml    learn.md   programming_the_mcu.md
favicon.ico          pinout
getting_started.md   pinout.md

This repo https://github.com/tinyvision-ai-inc/pico-ice/tree/main/Docs now is missing some very important files
needed for understanding the rp2040 functions with ice40UP5K.
I believe these are missing (ice_flash.md, ice_fpga.md, ice_led.md, ice_spi.md, ice_sram.md, and ice_usb.md).

I added several files in my test-dev branch in pico-ice/myDocs.
This should have said that I was ahead of tinyvision-ai-inc/pico-ice:main.

josuah, 2024-07-31:
Hello! The documentation evolved. Before, Sphinx was used (i.e. what ReadTheDocs uses). Now Doxygen is used, which permits to have the documentation for each of these features as part of the C source header themselves, and the HTML documentation is generated from here:
https://pico-ice.tinyvision.ai/modules.html

develone, 2024-07-31:
Thanks! Did the repo change just a few days ago?  My 2 pico-ice boards were shipped.  Looking forward to seeing how they work. Excited to start learning about this combo of rp2040 & ice40UK5K.

josuah, 2024-08-01:
It is possible that the firmware you receive on the pico-ice is not the latest one.
There are occasionally bugfixes published and a good precaution would be to download the latest release as soon as receiving the board, or indicate anyone using them to do so, in order to avoid confusing bugs that are already fixed:
<https://github.com/tinyvision-ai-inc/pico-ice/releases/latest>

There will be some changes to the repo, and the `develop` branch gets updated more frequently.
I do not remember the `main` branch being updated very lately.

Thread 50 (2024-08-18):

Problems when following the guide: "Programming the iCE40"

Thomas-514, 2024-08-18:
I ran into a few problems when following the guide "Programming the iCE40" more specifically the "Using APIO" section on the website.

Maybe they are because I'm working on a Mac (Intel Version)

After running "apio examples -f iCE40-UP5K/blink" the apio.ini looks like this:

```
[env]
board = iCE40-UP5K
top-module = rgb_test
```

Then it changes to:

```
[env]
board = pico-ice
top-module = main
```

The problem is, that in blink.v the main module is still named rgb_test. Thus, the build fails.

Further when executing "apio upload" the following command is executed.

dfu-util -d 1209:b1c0 -a 0 -D --reset hardware.bin

however, this then fails as the -D is not in front of hardware.bin. The correct command would be:

dfu-util -d 1209:b1c0 -a 0 --reset -D hardware.bin

Not sure if those things could be fixed by you or the guys from Apio. Just wanted to let you know.

Best Thomas

josuah, 2024-08-18:
Many thanks @Thomas-51! There will be some work coming on the pico-ice, this will be the occasion to review it.

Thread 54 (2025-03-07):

Missing link destination for programming default firmware.

aloeppert, 2025-03-07:
Hi all,

I just received my ice board and hit a speed bump.

From: https://github.com/tinyvision-ai-inc/pico-ice/releases/
there is a bit of text that says: See the [documentation](https://pico-ice.tinyvision.ai/md_programming_the_mcu.html) for installing it into the pico-ice.

and unfortunately that link doesn't resolve and I get a 404 error.
https://pico-ice.tinyvision.ai/md_programming_the_mcu.html

Regards,
Anthony

aloeppert, 2025-03-07:
Poking around it seems extra underscores are needed around "the".
https://pico-ice.tinyvision.ai/md_programming__the__mcu.html

I don't know if finding all the incorrect references and fixing them OR creating a link on the server to point to the existing file is a better solution.

josuah, 2025-03-07:
The documentation system switched to Doxygen, and as a result the URLs changed.
This got updated everywhere on the releases pages directly.

Thank you!

aloeppert, 2025-03-07:
Thanks for updating the release area.

FYI: From https://pico-ice.tinyvision.ai/md_getting__started.html the programming link is broken too.
See [Programming the RP2040](https://pico-ice.tinyvision.ai/md_programming_the_mcu.html) for how to load this firmware file.

I figured it out that in the left side panel, I can click there, but it was a bit confusing as a new user.
I'm looking forward to experimenting with the board!

josuah, 2025-05-11:
Thank you, at last I could save some time to come back to this and fix it!

Closed 2025-03-07.

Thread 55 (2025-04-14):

Programming the iCE40 does not work

gremarsl, 2025-04-14:
Hey there,
I followed your drag-and-drop instructions on https://pico-ice.tinyvision.ai/md_programming__the__fpga.html.

Step1-Step3 looks good, unfortunately step 4 is not successful. Copying the .uf2 file to the pico-ice usb-device works. But rebooting does not happen when unplugging and reconnecting the device to the pc again. My previously copied file is gone. The default *.uf2 file is there again.

What I tried to convert the .bin to uf2:
1. >bin2uf2 -o gateware.uf2 gateware.bin
2. >bin2uf2 -f 0x792e7263 -o gateware.uf2 0x01230000 gateware.bin
3. >python $(pybin2uf2) gateware.bin -b 0x00000000 -o gateware.uf2

What am I doing wrong? Could you provide me some help on this issue?

Thanks in advance.
Best regards
Marcel

gremarsl, 2025-04-18:
This issue could be solved by switching to dfu-util to flash a .bin instead of using the *.uf2 drag-and-drop mechanism.

josuah, 2025-04-18:
Thank you @gremarsl for the follow-up! Good thing that here is a fallback mechanism.
We will still keep an eye on the issue as it's better of everything works.
Could we know which operating system you use for the record?
The [`pico2-ice`](https://pico2-ice.tinyvision.ai/) will be an opportunity to fix this, via a different "drag-and-drop" programming method.

Closed 2025-04-18.

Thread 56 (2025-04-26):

dfu download sometimes hangs

MrJake222, 2025-04-26:
```
dfu-util -d 1209:b1c0 -a "iCE40 DFU (CRAM)" -D cdark.bin
dfu-util 0.11

Copyright 2005-2009 Weston Schmidt, Harald Welte and OpenMoko Inc.
Copyright 2010-2021 Tormod Volden and Stefan Schmidt
This program is Free Software and has ABSOLUTELY NO WARRANTY
Please report bugs to http://sourceforge.net/p/dfu-util/tickets/

dfu-util: Warning: Invalid DFU suffix signature
dfu-util: A valid DFU suffix will be required in a future dfu-util release
Opening DFU capable USB device...
Device ID 1209:b1c0
Run-Time device DFU version 0101
Claiming USB DFU Interface...
Setting Alternate Interface #1 ...
Determining device status...
DFU state(2) = dfuIDLE, status(0) = No error condition is present
DFU mode device DFU version 0101
Device returned transfer size 256
Copying data from PC to DFU device
Download        [=========================] 100%       104090 bytes
Download done.
DFU state(7) = dfuMANIFEST, status(0) = No error condition is present
DFU state(8) = dfuMANIFEST-WAIT-RESET, status(0) = No error condition is present
Resetting USB to switch back to runtime mode

... long hang ...
make: *** [../Makefile:85: prgcram] Error 74
```

Pretty annoying.

MrJake222, 2025-04-27:
Investigation. This happens:

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

The endpoint buffer register (0x84 = EP0 out buffer control) is already in use (available for the hw controller for consumption). This crash occurs after `Resetting USB to switch back to runtime mode`. Stack trace always follows:
- `ice_usb_uart_tx_from_cdc`
- `tud_cdc_n_read`
- ...
- `*ep->buffer_control & USB_BUF_CTRL_AVAIL` is true

The SDK doesn't handle `libusb_reset_device()` well.

josuah, 2025-04-27:
Thank you for this investigation!

It seems like someone also came upon this bug long ago: https://github.com/hathach/tinyusb/issues/2556

What happens if you [comment these lines](https://github.com/hathach/tinyusb/blob/b5d4d0f6237ecaf78b2548e5c4a08810e0957066/src/portable/raspberrypi/rp2040/rp2040_usb.c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)? This might not be a good solution, but depending on where it crashes next, this can help understand why this happened.

I will try to collect time  to reproduce the issue.

josuah, 2025-04-27:
**TL;DR: maybe we have a race condition somewhere in the pico-ice-sdk code, or in the tinyUSB driver**

The `buffer_control` field is a hardware register:

https://github.com/hathach/tinyusb/blob/master/src/portable/raspberrypi/rp2040/rp2040_usb.h#L61-L62
```c
typedef struct hw_endpoint
{
...
    // Buffer control register
    io_rw_32 *buffer_control;
...
};
```

As far as I understand the RP2040 USB driver on TinyUSB source, this flag is set here:

https://github.com/hathach/tinyusb/blob/b5d4d0f6237ecaf78b2548e5c4a08810e0957066/src/portable/raspberrypi/rp2040/rp2040_usb.c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
```c
prepare_ep_buffer()
{
  uint32_t buf_ctrl = buflen | USB_BUF_CTRL_AVAIL;
  ...
  return buf_ctrl;
}
```

It is only called in this function:

https://github.com/hathach/tinyusb/blob/b5d4d0f6237ecaf78b2548e5c4a08810e0957066/src/portable/raspberrypi/rp2040/rp2040_usb.c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

```c
hw_endpoint_start_next_buffer()
{
  uint32_t buf_ctrl = prepare_ep_buffer(ep, 0) | USB_BUF_CTRL_SEL;
...
  _hw_endpoint_buffer_control_set_value32(ep, buf_ctrl);
}
```

`_hw_endpoint_buffer_control_set_value32()` then calls `_hw_endpoint_buffer_control_update32()` in which the panic happens.

It does not look like this can cause a problem, as when `_hw_endpoint_buffer_control_update32()` returns, the flag is cleared. But if running this from the main context, and then an IRQ happens while this runs, and this is called again from the IRQ, then it becomes a race condition and the flag can be set twice (which the check detects and panic()'s).

I am not entirely sure that this is the problem, but that could be one thing I need to check from where that code is used...

MrJake222, 2025-04-27:
This also mentions a race condition: https://github.com/hathach/tinyusb/pull/2474

> It does not look like this can cause a problem, as when `_hw_endpoint_buffer_control_update32()` returns, the flag is cleared. But if running this from the main context, and then an IRQ happens while this runs, and this is called again from the IRQ, then it becomes a race condition and the flag can be set twice (which the check detects and panic()'s).

I don't get where the flag is cleared. The function ends with `*ep->buffer_control = value;`, which can definitely leave this flag set.

I think the issue here is that while reset, the device loses its ownership of the endpoints (kinda...). With [this minimal example](https://gist.github.com/MrJake222/3319c098bf4b9c0cda7829077e3c95d0) I was able to reproduce the problem.
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

The issue does not appear when [this line](https://github.com/tinyvision-ai-inc/pico-ice-sdk/blob/df9cf67bd46706c46de85ec8272354057275c14a/src/ice_usb_uart.c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) is commented out (no continuous reading).
I guess tinyusb doesn't stop the reading when init is in progress. Or we should check it somehow? "If endpoint is open then read"? The comms follow with the usb device reinitialization:

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

MrJake222, 2025-04-27:
> I guess tinyusb doesn't stop the reading when init is in progress. Or we should check it somehow? "If endpoint is open then read"? The comms follow with the usb device reinitialization:

Aaand I fixed it with `tud_ready()` haha. I'll make a pull request.

josuah, 2025-05-06:
Closing this now that https://github.com/tinyvision-ai-inc/pico-ice-sdk/pull/69 is merged.

This will be part of the next release as soon as things are rebased.

Thanks again for the investigation.

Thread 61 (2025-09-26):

ICE_DONE does not meet digital voltage input high spec...

frohro, 2025-09-26:
The pico-ice and pico2-ice are on the hairy edge of not meeting the V_IH spec for the RP2040 or RP2350B.   In my experience, the pico-ice worked, but the pico2-ice did not.  Page 615 of the datasheet for the RP2040 say 2 volts is needed, and that is what my scope measured on the pico2--ice.  The pico-ice was about 2.2V, which worked, but the LED was blindingly bright, so my old eyes could not read pin numbers without covering the CDONE LED up.
Sorry to report this hardware bug.
Rob

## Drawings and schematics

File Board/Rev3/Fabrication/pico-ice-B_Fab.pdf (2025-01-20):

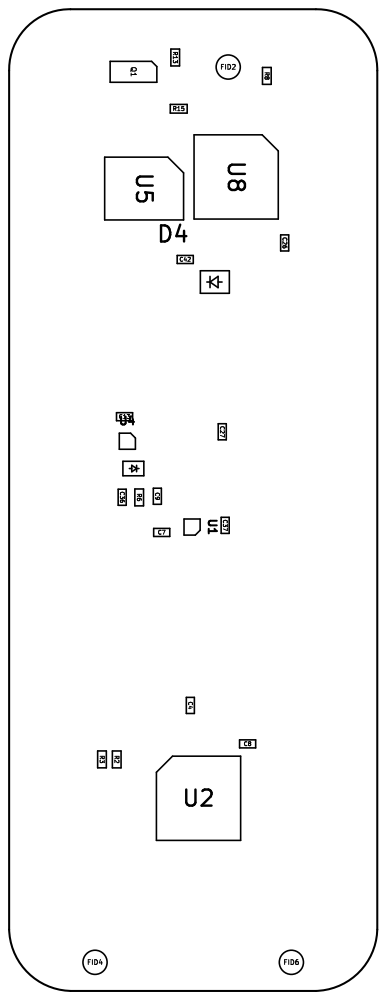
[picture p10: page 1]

Id: 1/1 Title: pico-ice

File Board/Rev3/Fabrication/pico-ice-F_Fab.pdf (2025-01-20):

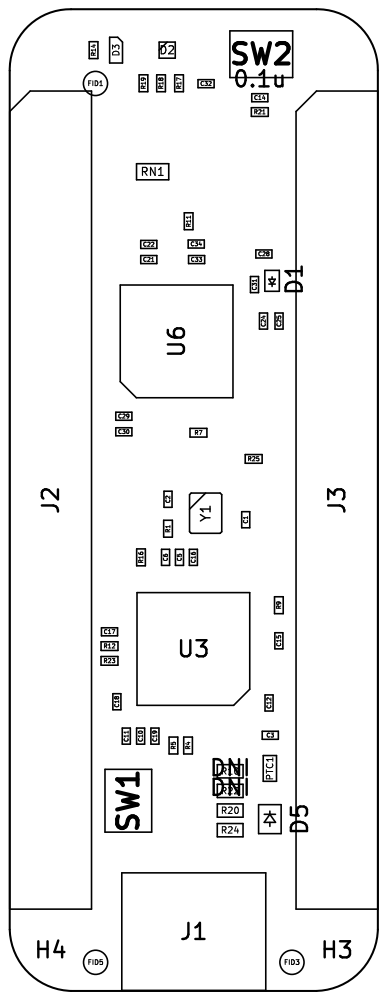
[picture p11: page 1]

Id: 1/1 Title: pico-ice

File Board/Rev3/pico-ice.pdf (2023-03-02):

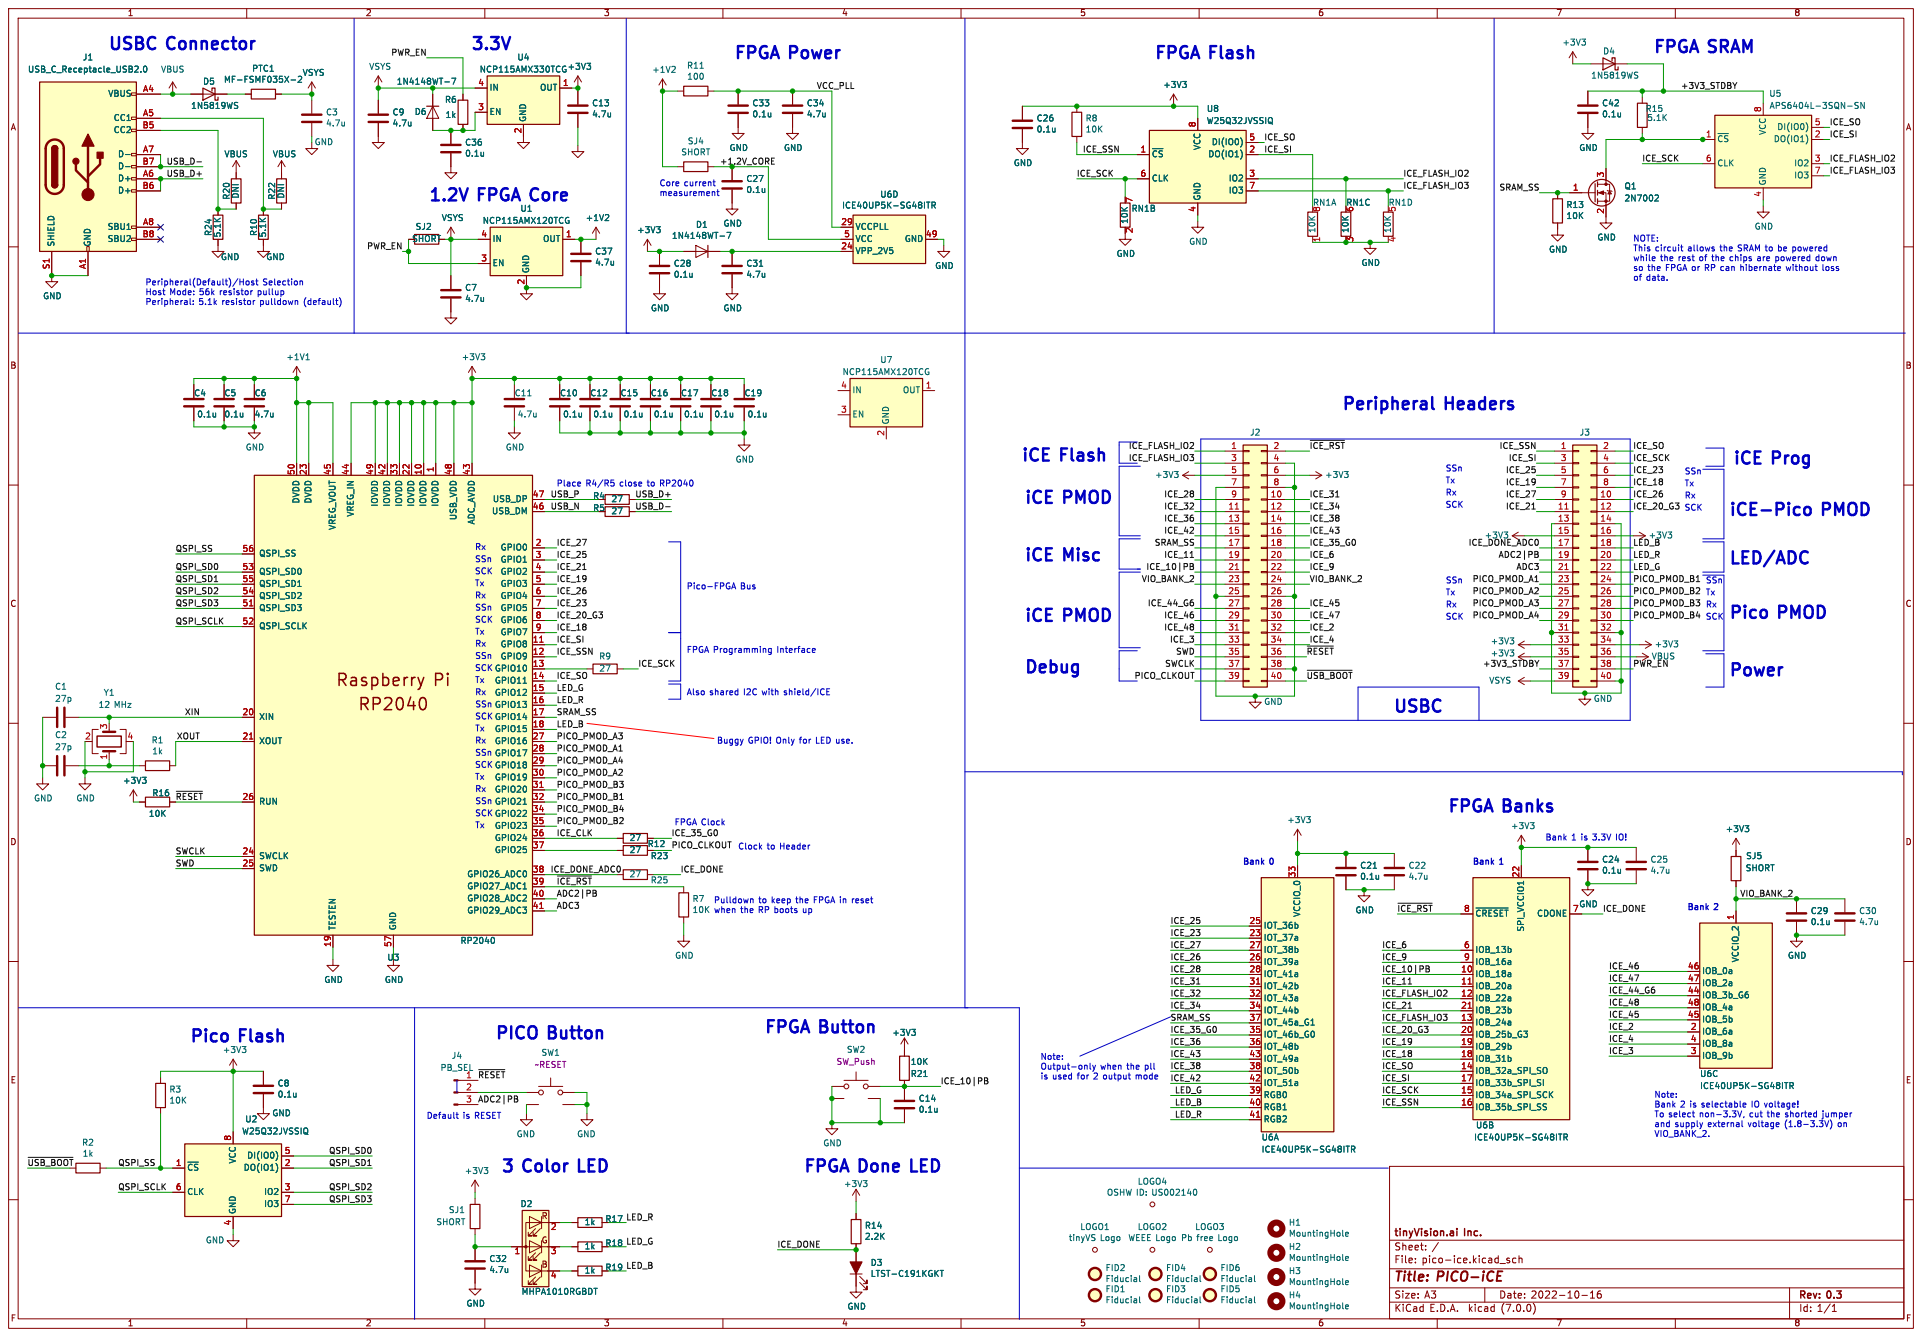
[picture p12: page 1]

NOTE: This circuit allows the SRAM to be powered while the rest of the chips are powered down

so the FPGA or RP can hibernate without loss of data.

SSn SCK Clock to Header SCK

1 IOVDD 10 GPIO8 11 GPIO9 12 GPIO10 13 GPIO11 14 GPIO12 15 GPIO13 16 GPIO14 17 GPIO15 18 TESTEN 19 GPIO0 2 XIN 20 XOUT 21 IOVDD 22 DVDD 23 SWCLK 24 SWD 25 RUN 26 GPIO16 27 GPIO17 28 GPIO18 29 GPIO1 3 GPIO19 30 GPIO20 31 GPIO21 32 IOVDD 33 GPIO22 34 GPIO23 35 GPIO24 36 GPIO25 37 GPIO26_ADC0 38 GPIO27_ADC1 39 GPIO2 4 GPIO28_ADC2 40 GPIO29_ADC3 41 IOVDD 42 ADC_AVDD 43 VREG_IN 44 VREG_VOUT 45 USB_DM 46 USB_DP 47 USB_VDD 48 IOVDD 49 GPIO3 5 DVDD 50 QSPI_SD3 51 QSPI_SCLK 52 QSPI_SD0 53 QSPI_SD2 54 QSPI_SD1 55 QSPI_SS 56 GND 57 GPIO4 6 GPIO5 7 GPIO6 8 GPIO7 9 +3V3 R16

1 IOVDD 10 GPIO8 11 GPIO9 12 GPIO10 13 GPIO11 14 GPIO12 15 GPIO13 16 GPIO14 17 GPIO15 18 TESTEN 19 GPIO0 2 XIN 20 XOUT 21 IOVDD 22 DVDD 23 SWCLK 24 SWD 25 RUN 26 GPIO16 27 GPIO17 28 GPIO18 29 GPIO1 3 GPIO19 30 GPIO20 31 GPIO21 32 IOVDD 33 GPIO22 34 GPIO23 35 GPIO24 36 GPIO25 37 GPIO26_ADC0 38 GPIO27_ADC1 39 GPIO2 4 GPIO28_ADC2 40 GPIO29_ADC3 41 IOVDD 42 ADC_AVDD 43 VREG_IN 44 VREG_VOUT 45 USB_DM 46 USB_DP 47 USB_VDD 48 IOVDD 49 GPIO3 5 DVDD 50 QSPI_SD3 51 QSPI_SCLK 52 QSPI_SD0 53 QSPI_SD2 54 QSPI_SD1 55 QSPI_SS 56 GND 57 GPIO4 6 GPIO5 7 GPIO6 8 GPIO7 9 U3 RP2040 R9

SSn SCK Default is RESET

Rx TxRx SCK Rx SSn SCK

Pulldown to keep the FPGA in reset when the RP boots up Also shared I2C with shield/ICE

is used for 2 output mode

LOGO3 Pb free Logo FID6 Fiducial

Id: 1/1 Title: PICO-iCE

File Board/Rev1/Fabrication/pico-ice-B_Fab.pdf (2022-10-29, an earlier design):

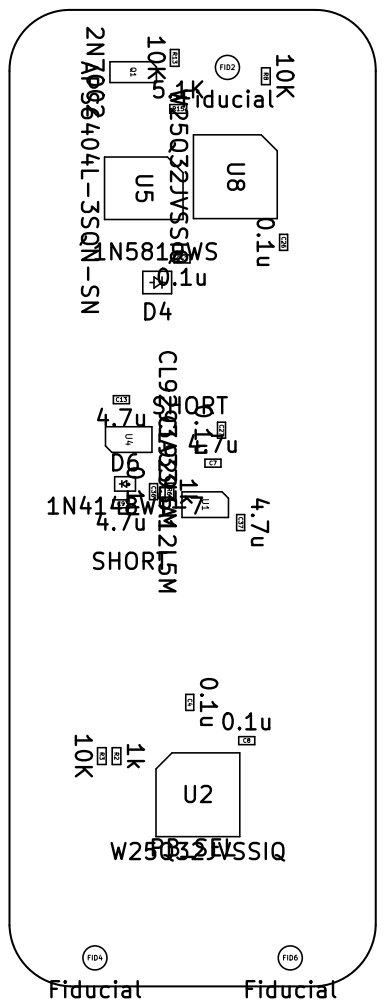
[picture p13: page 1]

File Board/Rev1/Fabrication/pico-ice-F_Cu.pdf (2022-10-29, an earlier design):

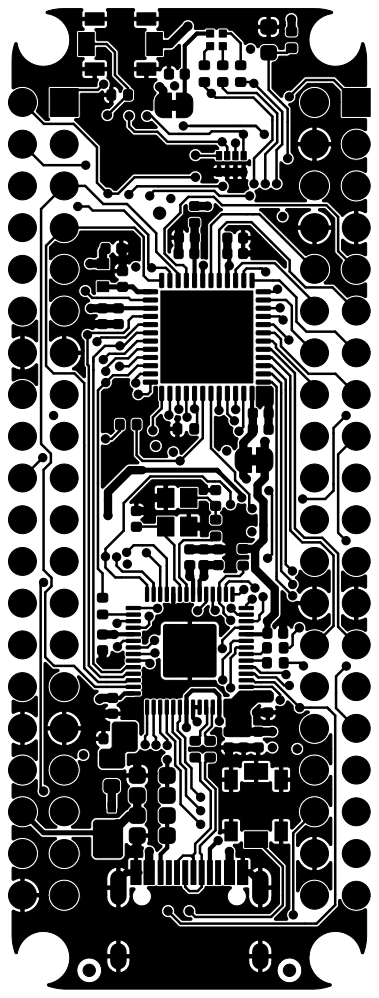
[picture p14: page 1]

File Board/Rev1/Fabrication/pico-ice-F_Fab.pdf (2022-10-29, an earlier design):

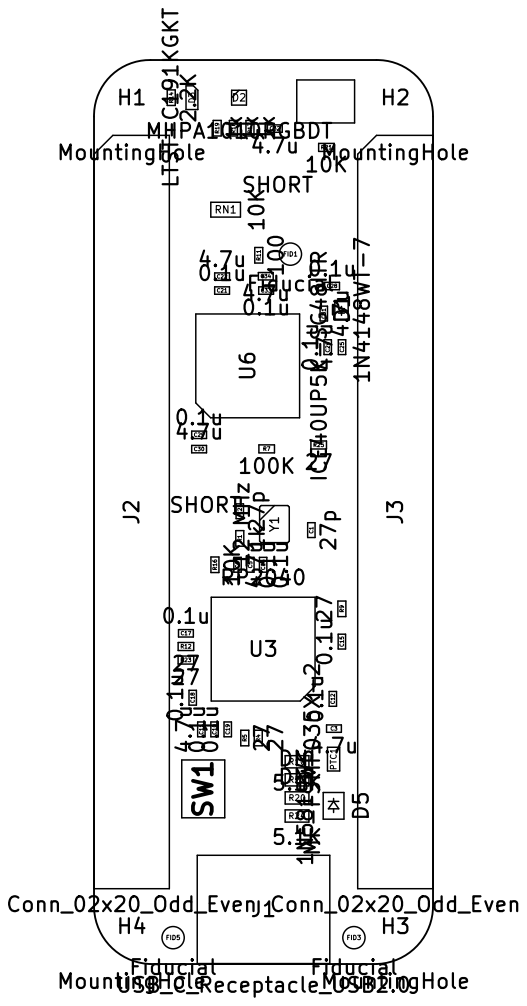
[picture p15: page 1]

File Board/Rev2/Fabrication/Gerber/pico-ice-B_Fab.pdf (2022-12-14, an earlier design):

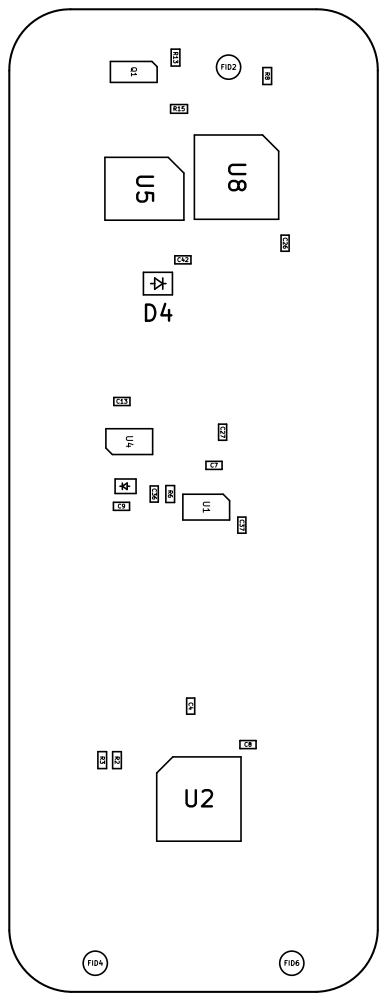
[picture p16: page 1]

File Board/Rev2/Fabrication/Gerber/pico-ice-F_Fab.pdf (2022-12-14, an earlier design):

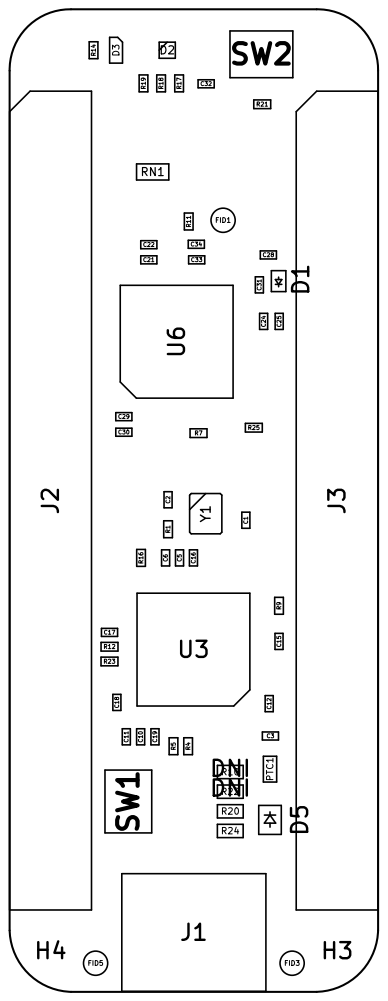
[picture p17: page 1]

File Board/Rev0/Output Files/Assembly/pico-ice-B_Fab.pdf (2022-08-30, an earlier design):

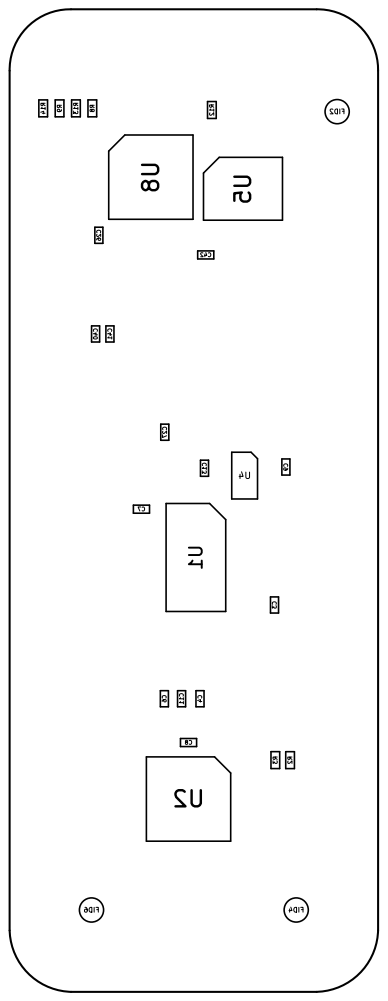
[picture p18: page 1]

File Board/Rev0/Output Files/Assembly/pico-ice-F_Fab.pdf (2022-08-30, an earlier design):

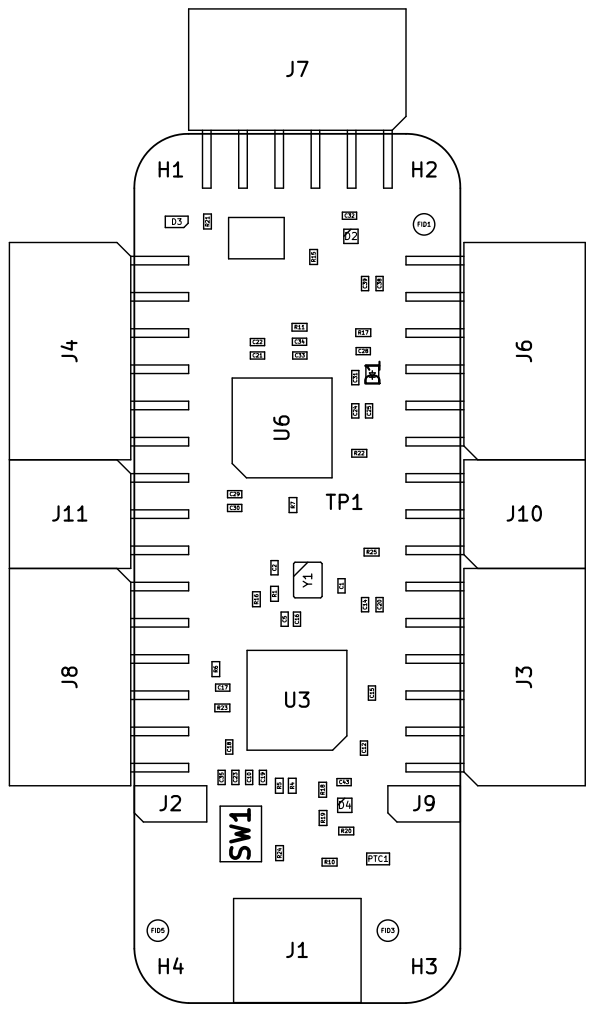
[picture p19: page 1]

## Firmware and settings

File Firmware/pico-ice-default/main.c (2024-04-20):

/*
 * MIT License
 *
 * Copyright (c) 2023 tinyVision.ai
 *
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
 * THE SOFTWARE IS PROVIDED "AS IS", WITHOUT WARRANTY OF ANY KIND, EXPRESS OR
 * IMPLIED, INCLUDING BUT NOT LIMITED TO THE WARRANTIES OF MERCHANTABILITY,
 * FITNESS FOR A PARTICULAR PURPOSE AND NONINFRINGEMENT. IN NO EVENT SHALL THE
 * AUTHORS OR COPYRIGHT HOLDERS BE LIABLE FOR ANY CLAIM, DAMAGES OR OTHER
 * LIABILITY, WHETHER IN AN ACTION OF CONTRACT, TORT OR OTHERWISE, ARISING FROM,
 * OUT OF OR IN CONNECTION WITH THE SOFTWARE OR THE USE OR OTHER DEALINGS IN THE
 * SOFTWARE.
 */

// pico-sdk
#include "pico/stdio.h"
#include "hardware/irq.h"
#include "hardware/gpio.h"
#include "hardware/uart.h"

// pico-ice-sdk
#include "ice_usb.h"
#include "ice_fpga.h"
#include "ice_led.h"

#define UART_TX_PIN 0
#define UART_RX_PIN 1

#define DOC_FORWARD_SPI \
"https://pico-ice.tinyvision.ai/group__ice__usb.html#autotoc_md2"

#define DOC_DEFAULT_FIRMWARE \
"https://github.com/tinyvision-ai-inc/pico-ice/tree/main/Firmware/pico-ice-default"

// for repl_ungetchar() to take back the last character from repl_getchar():
int repl_last_char;
bool repl_last_held;

static int repl_getchar(void)
{
    int c;

    if (repl_last_held) {
        repl_last_held = false;
        return repl_last_char;
    }

    c = getchar_timeout_us(0);
    if (c == PICO_ERROR_TIMEOUT)
        return c;

    if (c == '\r' || c == '\n') {
        printf("\r\n");
    } else {
        putchar(c);
    }
    return c;
}

static void repl_ungetchar(int c)
{
    assert(!repl_last_held);
    repl_last_char = c;
    repl_last_held = true;
}

static inline bool repl_parse_error(char *msg, char c)
{
    // reset whatever was being input
    repl_last_held = false;

    printf("\nerror: expected %s got '%c'\n", msg, c);
    return false;
}

static bool repl_parse_newline(void)
{
    int c;

    switch (c = repl_getchar()) {
    case '\r':
    case '\n':
    case EOF:
        return true;
    default:
        repl_ungetchar(c);
        return repl_parse_error("newline", c);
    }
}

static void repl_command_version(void)
{
    if (!repl_parse_newline()) {
        return;
    }
    printf("pico-ice-sdk %s\r\n", VERSION);
}

static void repl_prompt(void)
{
    printf("\x1b[1mpico-ice>\x1b[m ");
}

int main(void)
{
    // Enable USB-CDC #0 (serial console)
    stdio_init_all();

    // Enable the physical UART
    uart_init(uart0, 115200);
    gpio_set_function(UART_TX_PIN, GPIO_FUNC_UART);
    gpio_set_function(UART_RX_PIN, GPIO_FUNC_UART);

    // Let the FPGA start
    ice_fpga_init(12);
    ice_fpga_start();

    // Configure USB as defined in tusb_config.h
    ice_usb_init();

    // Prevent the LEDs from glowing slightly
    ice_led_init();

    // Print repl prompt
    repl_prompt();

    while (true) {
        tud_task();

        int chr = repl_getchar();
        if (chr == PICO_ERROR_TIMEOUT)
            continue;

        // not timeout, something received

        switch (chr) {
        case 'v':
            repl_command_version();
            break;
        default:
            printf("\r\n");
            printf("pico-ice default firmware\r\n", VERSION);
            printf("   %s\r\n", DOC_DEFAULT_FIRMWARE);
            printf("\r\n");
            printf("Serial port #0 - this shell, with commands:\r\n");
            printf("  v - print pico-ice-sdk version\r\n");
            printf("\r\n");
            printf("Serial port #1 - forwarding to UART\r\n");
            printf("  UART TX on RP0 = ICE27\r\n");
            printf("  UART RX on RP1 = ICE25\r\n");
            printf("\r\n");
            printf("Serial port #2 - forwarding to SPI:\r\n");
            printf("  %s\r\n", DOC_FORWARD_SPI);
            printf("\r\n");
            break;
        }

        // reprint prompt
        repl_prompt();
    }

    return 0;
}

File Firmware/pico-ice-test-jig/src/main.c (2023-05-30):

/*
 * MIT License
 *
 * Copyright (c) 2023 tinyVision.ai
 *
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
 * THE SOFTWARE IS PROVIDED "AS IS", WITHOUT WARRANTY OF ANY KIND, EXPRESS OR
 * IMPLIED, INCLUDING BUT NOT LIMITED TO THE WARRANTIES OF MERCHANTABILITY,
 * FITNESS FOR A PARTICULAR PURPOSE AND NONINFRINGEMENT. IN NO EVENT SHALL THE
 * AUTHORS OR COPYRIGHT HOLDERS BE LIABLE FOR ANY CLAIM, DAMAGES OR OTHER
 * LIABILITY, WHETHER IN AN ACTION OF CONTRACT, TORT OR OTHERWISE, ARISING FROM,
 * OUT OF OR IN CONNECTION WITH THE SOFTWARE OR THE USE OR OTHER DEALINGS IN THE
 * SOFTWARE.
 */

// libc
#include <stdarg.h>
#include <stdio.h>
#include <stdlib.h>

// pico-sdk
#include "hardware/irq.h"

// pico-ice-sdk
#include "boards/pico_ice.h"
#include "ice_usb.h"
#include "ice_fpga.h"
#include "ice_led.h"
#include "ice_sram.h"

#define FIRST_GPIO_PIN      0
#define LAST_GPIO_PIN       29
#define FPGA_BUTTON_PIN     ICE_FPGA_21_PIN // Mirrored from the FPGA
#define FPGA_HIGH_Z_PIN     ICE_FPGA_20_PIN
#define CHAIN_IN_PIN        ICE_FPGA_26_PIN
#define CHAIN_OUT_PIN       ICE_FPGA_27_PIN

#define ARRAY_LENGTH(x) (sizeof(x) / sizeof(*(x)))

static bool g_step_failed;
static bool g_test_failed;
static bool g_any_failed;

const enum {
    TYPE_FREE_PIN = 0,
    TYPE_FPGA_PIN,
    TYPE_SPI_PIN,
    TYPE_LED_PIN,
    TYPE_SYSTEM_PIN,
} pin_type[30] = {
    // shared Pmod pins
    [0]     = TYPE_FPGA_PIN,
    [1]     = TYPE_FPGA_PIN,
    [2]     = TYPE_FPGA_PIN,
    [3]     = TYPE_FPGA_PIN,
    [4]     = TYPE_FPGA_PIN,
    [5]     = TYPE_FPGA_PIN,
    [6]     = TYPE_FPGA_PIN,
    [7]     = TYPE_FPGA_PIN,

    // SPI pins
    [8]     = TYPE_SPI_PIN,
    [9]     = TYPE_SPI_PIN,
    [10]    = TYPE_SPI_PIN,
    [11]    = TYPE_SPI_PIN,
    [14]    = TYPE_SPI_PIN,

    // LED pins
    [ICE_LED_RED_PIN]       = TYPE_LED_PIN,
    [ICE_LED_GREEN_PIN]     = TYPE_LED_PIN,
    [ICE_LED_BLUE_PIN]      = TYPE_LED_PIN,

    // system pins
    [FPGA_BUTTON_PIN]       = TYPE_SYSTEM_PIN,
    [FPGA_HIGH_Z_PIN]       = TYPE_SYSTEM_PIN,
    [ICE_FPGA_CRESET_B_PIN] = TYPE_SYSTEM_PIN,
    [ICE_FPGA_CDONE_PIN]    = TYPE_SYSTEM_PIN,

    // FPGA clock pin
    [24]    = TYPE_FPGA_PIN,
};

static void test_sleep_ms(uint32_t delay_ms) {
    for (uint32_t i = 0; i < delay_ms; i += 1) {
        tud_task();
        ice_usb_sleep_ms(1);
    }
}

static void test_assert(bool exp) {
    if (!exp) {
        g_step_failed = true;
        g_test_failed = true;
        g_any_failed = true;
    }
}

static void test_step_printf(char const *fmt, ...)
{
    va_list va;

    va_start(va, fmt);
    printf(" %s - ", g_step_failed ? "FAIL" : "PASS");
    vprintf(fmt, va);
    printf("\n");
}

static bool test_start(char const *desc) {
    printf("\n%s\n", desc);
    g_test_failed = false;
}

static void test_end(void) {
    if (!g_test_failed) {
        printf(" PASS\n");
    }
}

static void test_summary(void (*led_fn)(bool)) {
    if (g_any_failed) {
        ice_led_init();
        ice_led_red(true);
        printf("\nFAIL - Some tests above failed\n");
    } else {
        ice_led_init();
        led_fn(true);
        printf("\nPASS - All tests passed\n");
    }
}

static bool pull_output(uint pin, bool state) {
    // change state of SWDIO or SWCLK using pull-up and pull-down
    int pulls = state ? PADS_BANK0_GPIO0_PUE_BITS : PADS_BANK0_GPIO0_PDE_BITS;
    hw_write_masked(&padsbank0_hw->io[pin], pulls, PADS_BANK0_GPIO0_PUE_BITS | PADS_BANK0_GPIO0_PDE_BITS);
}

static bool button_pressed(void) {
    test_sleep_ms(1);
    return !gpio_get(FPGA_BUTTON_PIN);
}

static bool pin_is_drivable(uint8_t pin) {
    switch (pin_type[pin]) {
    case TYPE_SYSTEM_PIN:
        return false;
    default:
        return true;
    }
}

static bool pin_is_pulled_externally(uint8_t pin) {
    switch (pin_type[pin]) {
    case TYPE_SPI_PIN:
    case TYPE_LED_PIN:
    case TYPE_SYSTEM_PIN:
        return true;
    default:
        return false;
    }
}

static bool pin_set_all_input(void) {
    for (int i = FIRST_GPIO_PIN; i <= LAST_GPIO_PIN; i++) {
        gpio_init(i);
    }
}

static bool button_wait_press_release(void) {
    while (!button_pressed());
    while (button_pressed());
}

static bool fpga_pins_high_z(bool state) {
    gpio_put(FPGA_HIGH_Z_PIN, state);
}

static bool check_pin_state(int pin, bool state) {
    g_step_failed = false;
    test_assert(gpio_get(pin) == state);
    test_step_printf("%s(%d, %s)", __func__, pin, state ? "true" : "false");
}

static void check_pin_connected(int pin_i, int pin_o) {
    g_step_failed = false;
    gpio_set_dir(pin_o, GPIO_OUT);
    gpio_set_dir(pin_i, GPIO_IN);
    gpio_disable_pulls(pin_i);

    for (int i = 0; i < 10; i++) {
        gpio_put(pin_o, 0);
        test_sleep_ms(1);
        test_assert(gpio_get(pin_i) == 0);

        gpio_put(pin_o, 1);
        test_sleep_ms(1);
        test_assert(gpio_get(pin_i) == 1);
    }

    test_step_printf("%s(%d, %d)", __func__, pin_i, pin_o);
    gpio_set_dir(pin_o, GPIO_IN);
}

static void check_pin_not_connected(int pin_i, int pin_o) {
    g_step_failed = false;
    gpio_set_dir(pin_o, GPIO_OUT);
    gpio_set_dir(pin_i, GPIO_IN);
    gpio_set_pulls(pin_i, true, false);

    for (int i = 0; i < 10; i++) {
        gpio_put(pin_o, 0);
        test_sleep_ms(1);
        test_assert(gpio_get(pin_i) == 1);

        gpio_put(pin_o, 1);
        test_sleep_ms(1);
        test_assert(gpio_get(pin_i) == 1);
    }

    test_step_printf("%s(%d, %d)", __func__, pin_i, pin_o);
    gpio_set_dir(pin_o, GPIO_IN);
    gpio_disable_pulls(pin_i);
}

static void check_free_pin_consistent(int pin) {
    g_step_failed = false;
    gpio_set_dir(pin, GPIO_IN);

    for (int i = 0; i < 10; i++) {
        gpio_set_pulls(pin, true, false); // pull up
        test_sleep_ms(1);
        test_assert(gpio_get(pin) == 1);

        gpio_set_pulls(pin, false, true); // pull down
        test_sleep_ms(1);
        test_assert(gpio_get(pin) == 0);
    }

    test_step_printf("%s(%d)", __func__, pin);
}

static void check_pulled_pin_consistent(int pin) {
    g_step_failed = false;
    gpio_set_dir(pin, GPIO_OUT);

    for (int i = 0; i < 10; i++) {
        gpio_put(pin, 1);
        test_sleep_ms(1);
        test_assert(gpio_get(pin) == 1);

        gpio_put(pin, 0);
        test_sleep_ms(1);
        test_assert(gpio_get(pin) == 0);
    }

    test_step_printf("%s(%d)", __func__, pin);
    gpio_set_dir(pin, GPIO_IN);
}

static const uint8_t dummy_range[] = {
    0x00, 0x01, 0x02, 0x03, 0x04, 0x05, 0x06, 0x07,
    0x08, 0x09, 0x0A, 0x0B, 0x0C, 0x0D, 0x0E, 0x0F,
    0x10, 0x11, 0x12, 0x13, 0x14, 0x15, 0x16, 0x17,
    0x18, 0x19, 0x1A, 0x1B, 0x1C, 0x1D, 0x1E, 0x1F,
    0x20, 0x21, 0x22, 0x23, 0x24, 0x25, 0x26, 0x27,
    0x28, 0x29, 0x2A, 0x2B, 0x1C, 0x2D, 0x2E, 0x2F,
};
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

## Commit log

2022-06-19 Fixed PMOD connections and other major changes. Needs detailed review.
    [pico-ice.kicad_sch]
2022-06-21 Moved schematic files around. No design changes after v0.1 of files for review.
2022-06-22 Moved files for review to Review, reallocated pinlist on RP
    [pico-ice.kicad_sch]
2022-06-24 Added external clock from RP to external header
    [pico-ice.kicad_sch]
2022-06-25 Added MPN's for a few parts
    [pico-ice.kicad_sch]
2022-07-05 Added MPN and footprint.
    [pico-ice.kicad_pcb, pico-ice.kicad_sch]
2022-07-07 Rough placement, needs work to compress this and center everything into 0.1" centers
    [pico-ice.kicad_pcb, pico-ice.kicad_sch]
2022-07-10 Finished the preliminary placement.
    [pico-ice.kicad_pcb, pico-ice.kicad_sch]
2022-07-12 Minor net reallocation
    [pico-ice.kicad_sch]
2022-07-14 Reduce the board outline.
    [pico-ice.kicad_pcb, pico-ice.kicad_sch]
2022-07-15 Replaced USB connector.
    [pico-ice.kicad_pcb, pico-ice.kicad_sch]
2022-08-01 Synced the latest design files.
    [pico-ice.kicad_pcb, pico-ice.kicad_sch]
2022-08-11 Minor changes to pinouts of headers.
    [pico-ice.kicad_pcb, pico-ice.kicad_sch]
2022-08-15 Finished the routing
    [pico-ice.kicad_pcb]
2022-08-16 Updated the routing.
    [pico-ice.kicad_pcb, pico-ice.kicad_sch]
2022-08-17 Cleaned up silkscreen
    [pico-ice.kicad_pcb]
2022-08-17 Added a few pin numbers on the silkscreen
    [pico-ice.kicad_pcb]
2022-08-18 Updated the silkscreen layer
    [pico-ice.kicad_pcb, pico-ice.kicad_sch]
2022-08-18 Silkscreen changes
    [pico-ice.kicad_pcb]
2022-08-19 Updated the logo
    [pico-ice.kicad_pcb]
2022-08-20 Updated SCH/PCB
    [pico-ice.kicad_pcb, pico-ice.kicad_sch]
2022-08-22 Added block diagram and rendering files. Changed layers for logo and board name to be the mask layer
    [pico-ice.kicad_pcb]
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2022-08-24 Consolidated BoM (changed out 1uF to 4.7uF), generated gerbers and other output files
    [pico-ice-B_Cu.gbr, pico-ice-B_Mask.gbr, pico-ice-B_Paste.gbr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]
2022-08-25 Changed author, added ibom
    [pico-ice.kicad_pcb]
2022-08-27 Docs: "RGB pin low = turned on" and different pinout than RP2040
    Fix #5
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2022-09-20 Docs: add pico-ice/ice.h and document bugs that the user could encounter by using the SDK
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2022-09-22 Initial version of v1: added diode on power, brought out USB power, removed redundant resistor on ICE_SCK
    [pico-ice.kicad_pcb, pico-ice.kicad_sch, pico-ice.sch]
2022-09-23 Changed Schottky part
    [pico-ice.kicad_sch]
2022-10-09 Modified pico pin assignments, changed LDO's to have enables
    [pico-ice.kicad_sch]
2022-10-10 Moved RP GPIO's around, redid schematic to show actual placement of headers
    [pico-ice.kicad_sch]
2022-10-13 Selectable Pico PB, power enable
    [pico-ice.kicad_sch]
2022-10-13 Fixed annotation on res network
    [pico-ice.kicad_sch]
2022-10-13 Replaced 1.2V with 3.3V standby on connector
    [pico-ice.kicad_sch]
2022-10-17 Cleaned up schematic, changed to 2x20 headers
    [pico-ice.kicad_pcb, pico-ice.kicad_sch]
2022-10-17 Minor changes to the header signal allocation.
    [pico-ice.kicad_sch]
2022-10-17 More cleanup, slight reassignment of pins again!
    [pico-ice.kicad_sch]
2022-10-17 More minor cleanup
    [pico-ice.kicad_sch]
2022-10-17 Fixed error in PMOD connections to the FPGA, was flipped around: checked that it matches the icebreaker for the dual-dual PMOD & single dual PMOD to the iCE40.
    [pico-ice.kicad_pcb, pico-ice.kicad_sch]
2022-10-18 Added USB host/peripheral selection using a jumper
    [pico-ice.kicad_sch]
2022-10-19 Changed USB selection jumper to 0603 resistors
    [pico-ice.kicad_sch]
2022-10-19 Finished the placement for a review.
    [pico-ice.kicad_pcb]
2022-10-19 Minor changes to placement
    [pico-ice.kicad_pcb]
2022-10-21 Finished the layout for a review.
    [pico-ice.kicad_pcb]
2022-10-21 Made a few refdes invisible on silk
    [pico-ice.kicad_pcb]
2022-10-21 Fixed disconnect of the PICO_PMOD_B[1:4]
    [pico-ice.kicad_sch]
2022-10-21 Moved a few traces apart, esp on the clock related signals. Led to a couple of unwired signals.
    [pico-ice.kicad_pcb]
2022-10-24 Clean silkscreen
    [pico-ice.kicad_pcb]
2022-10-25 Added silkscreen details, minor routing change to clear the logo
    [pico-ice.kicad_pcb]
2022-10-26 Added silkscreen for PMOD identification
    [pico-ice.kicad_pcb]
2022-10-29 Submitted v2 to fab house
    [BoM_pico-ice.csv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]
2022-10-29 Left out the final save!
    [pico-ice.kicad_pcb]
2022-12-01 Rev 2 with ice_si and so swapped on the RP2040
    [pico-ice.kicad_pcb, pico-ice.kicad_sch, pico-ice.sch]
2022-12-02 Fixed routing and also some silkscreen DRC's
    [pico-ice.kicad_pcb]
2022-12-02 Changed version on the board so it reads Rev2
    [pico-ice.kicad_pcb]
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2022-12-14 Added OSHW logo
    [pico-ice.kicad_pcb, pico-ice.kicad_sch]
2022-12-14 Cleaned up fab drawing, generated gerbers
    [pico-ice-B_Cu.gbr, pico-ice-B_Fab.gbr, pico-ice-B_Mask.gbr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]
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2023-03-02 Modified Pico PMOD assignments
    [pico-ice.kicad_pcb, pico-ice.kicad_sch, pico-ice.sch]
2023-03-02 Fixed debouncing for PB
    [pico-ice.kicad_sch]
2023-03-02 Changed LDO's to tiny packages for better thermal properties
    [pico-ice.kicad_sch]
2023-03-02 Changed net names of vbus, vdc to match pico naming
    [pico-ice.kicad_sch]
2023-03-07 Finish the routing for a review.
    [pico-ice.kicad_pcb, pico-ice.kicad_sch]
2023-03-07 Changed xtal to resonator after lab testing
    [pico-ice.kicad_pcb, pico-ice.kicad_sch]
2023-03-07 Revert "Changed xtal to resonator after lab testing"
    This reverts commit ae6d2ffb92b5ae32abb0e0d73cf8c0fd4f4cea6e.
    [pico-ice.kicad_pcb, pico-ice.kicad_sch]
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2023-04-03 Firmware/pico-ice-test: fix warning and errors from top.sv
    [main.c]
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2023-05-30 pico-ice-test-jig: fix compilation errors
    [main.c]
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2023-06-02 prevent TinyUSB to override our UART for logging
    [tusb_config.h]
2023-06-20 Docs: tip on shorting the BOOT pin to ground with tweezers
2023-07-19 pico-ice-default: prevent the LEDs from glowing
    [main.c]
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2023-09-01 Firmware: fix the FPGA not booting when programming via TinyUF2
    [main.c]
2023-10-16 Updated R10,R20,R22,R24 MPN & footprint assignment in sch. Updated footprint for U1, U4 where the pin 1 was rotated leading to improper assembly
    [pico-ice.kicad_pcb, pico-ice.kicad_sch]
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2023-12-08 Fix USB enumeration problem on macOS.
    [main.c]
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2023-12-20 usb: fix most/all dfu-util related problems
    [main.c]
2024-01-08 Firmware: fix the URL in the firmware after switching to Doxygen
    [main.c]
2024-04-20 Firmware: merge a bugfix in the pico-ice-sdk
2024-04-20 Fixed 10ms per-byte delay
    Replaced call to getchar with delay 0
    Now "timeout" is handled in main loop
    Repl responds only to valid characters (not timeouts)
    [main.c]
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2024-09-20 Fixed an error in the spi debug black image.
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2025-01-20 Fixed U1, U4 orientation on the fab drawing
    [pico-ice.kicad_pcb]
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2025-03-18 fix undriveable pin not being respected
    [run_tests_rp2040.py]
2025-03-20 Add missing shorts test and multiple checks
    [run_tests_rp2040.py]
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
